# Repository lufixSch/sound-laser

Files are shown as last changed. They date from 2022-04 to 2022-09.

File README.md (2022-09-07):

# Sound Laser

This repository contains the source code, 3D Models, Circuit/PCB designs and documentation of the Sound Laser bachelor thesis at the FH JOANNEUM.

The LaTex documentation is located in [docs/build/SoundLaser_Thesis.pdf](docs/build/SoundLaser_Thesis.pdf)

## Abstract

Parametric speakers are able to transmit audible sound with a beamforming effect using ultrasonic transducers. This work will describe the development of such a speaker as well as the software necessary to operate it.

In order to build this speaker it is explained how the beamforming effect occurs and how the number of transducers as well as distance between them influences its behaviour. Furthermore non-linear acoustics and why they can demodulate amplitude or frequency modulated signals are discussed.

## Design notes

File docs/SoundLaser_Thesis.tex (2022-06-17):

\documentclass[11pt, openright]{book} % defines Basic settings for my document

\input{src/config/index}

\makeglossaries

\begin{document}
  \input{src/pages/frontmater/glossaries.tex}
  \input{src/pages/index}
\end{document}

% \enlargethispage{\baselineskip} --> Einige Zeilen trotz Seitenumbruch noch auf die vorherige Seite bringen
% \section*{xyz} --> wird nicht im Inhaltsverzeichnis gezeigt

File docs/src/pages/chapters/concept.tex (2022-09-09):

\chapter{Concept}\label{sec:concept}

% \begin{enumerate}
%   \item Ultrasonic beamforming
%   \subitem Reason:
%   \subsubitem Smaller speaker
%   \subsubitem Better focus
%   \item Hexagon module
%   \subitem Reason:
%   \subsubitem Extendable/Combinable with multiple modules
%   \subitem Amplification for each module
%   \subitem digital input
%   \item Aiming with physical contraption
%   \subitem no phase shifting necessary
%   \subsubitem to much amplifier circuits
%   \subsubitem to much digital processing -> ?proof?
% \end{enumerate}

The basic idea of this project is to design a small, autonomous module which can be combined to a larger speaker-array with improved beamforming characteristics. This will give the opportunity to compare different arrangements and numbers of modules. A single module is hexagon-shaped in order to be arranged in a honeycomb like style. Each module is equipped with an onboard DAC and amplification circuit.\p
Because of their size and their more focused dispersion characteristics, ultrasonic transducers are used in this project. How audible sound can played over an ultrasonic transducer will be explained in section \secref{sec:theory:mod}.\p
The direction of the beam is not controlled by phase shifting because, every transducer would need it's own DAC and amplifier. Alternatively the direction is altered by a mechanical contraption.

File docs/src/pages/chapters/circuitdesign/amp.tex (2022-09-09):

\section{Amplifier}\label{sec:pcb:amp}

%\begin{enumerate}
  %\item Requirements
  %\subitem VCC >= 24V -> Why
  %\item pcb layout
%\end{enumerate}

Ultrasonic transducers have to be driven with a much higher voltage and current than a DAC can provide. Therefore an amplifier circuit was designed which employs the DAC voltage as input and generates a suitable output for the array of ultrasonic transducers.

\subsection{Circuit}

The amplifier (figure \ref{fig:pcb:amp_circuit}) consists of two sections. First a non-inverting amplifier circuit to amplify the input voltage. Further, a Class B power amplifier is used so the circuit is able to drive the high capacitive load of the transducers. The whole circuit is designed for single supply because the power supply only provides a positive voltage.

\begin{figure}
  \centering
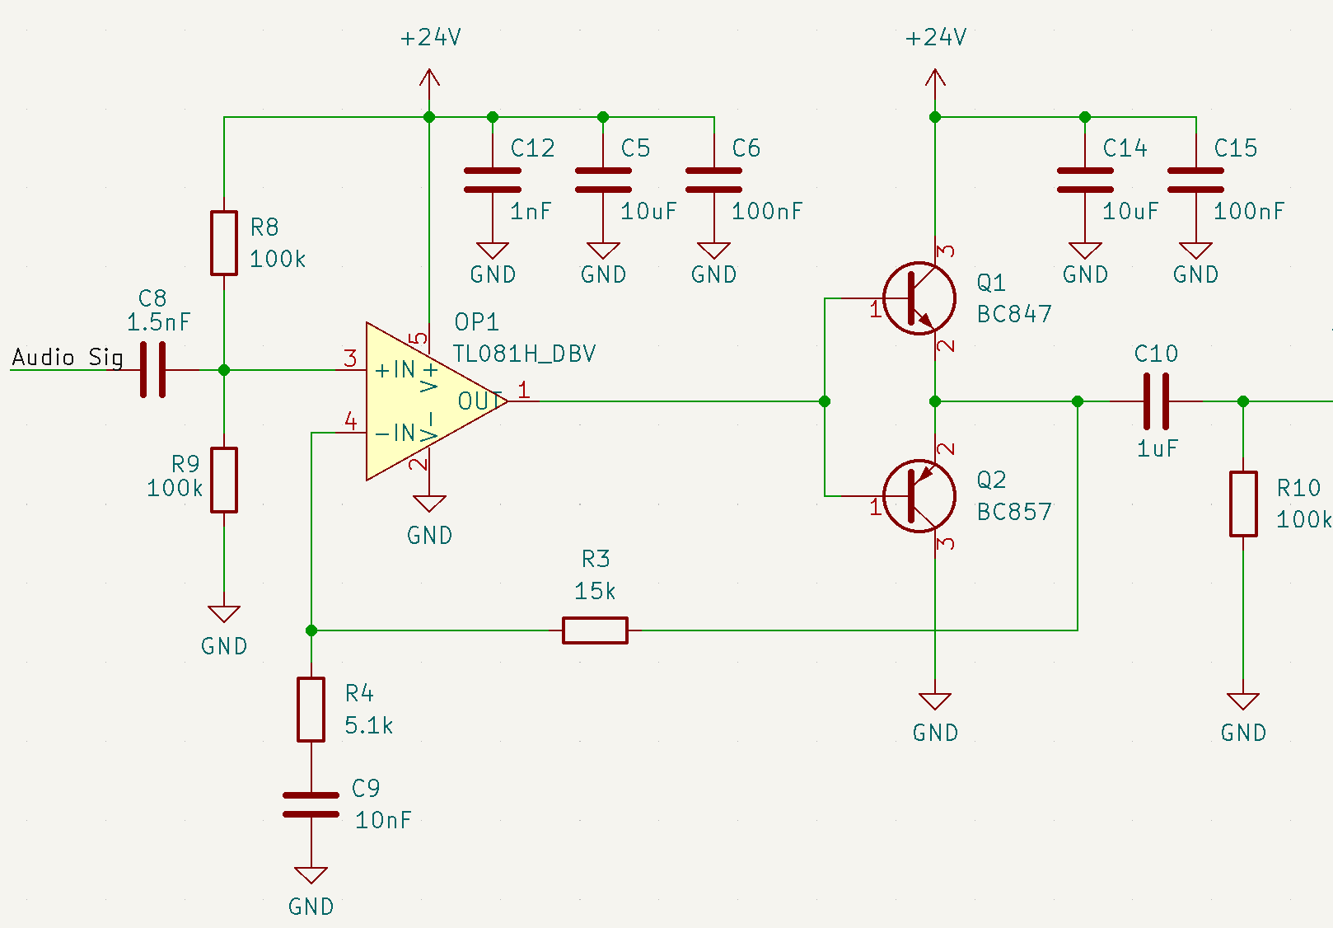
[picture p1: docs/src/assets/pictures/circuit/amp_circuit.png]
  
  \caption{Amplifier circuit design}\label{fig:pcb:amp_circuit}
\end{figure}

\subsubsection*{Voltage input}
%
\comp{C8} is used to filter the DC part of the input signal. \comp{R8} and \comp{R9} then generate a virtual ground (operating point) at $12\,V$. For AC signals a DC power supply can be seen as short circuit. This will result in \comp{R8} and \comp{R9} being parallel (figure \ref{fig:pcb:amp_hp}). Combined with \comp{C8} they create a simple high-pass which can be calculated for a specific cut-off frequency.
%
\begin{align}
  R_8 || R_9 &= \frac{1}{2} R_{8/9} \pmath
  \cfrac{U_a}{U_{in}} &= \cfrac{sC_8\cdot \frac{1}{2}R_{R8/9}}{1 + sC_8\cdot \frac{1}{2}R_{8/9}} \pmath
  f_g &= \cfrac{1}{2 \pi C_8 \cdot \frac{1}{2}R_{R8/9}} \pmath
  C_8 &= \cfrac{1}{2 \pi f_g \cdot \frac{1}{2}R_{R8/9}}
\end{align}
%
As cut-off frequency $4\,kHz$ was chosen and for \comp{R8} and \comp{R9} a value of $100\,k\Omega$ was selected. This results in a capacity of $1.5\,nF$ for \comp{C8}.
%
\begin{figure}
  \centering
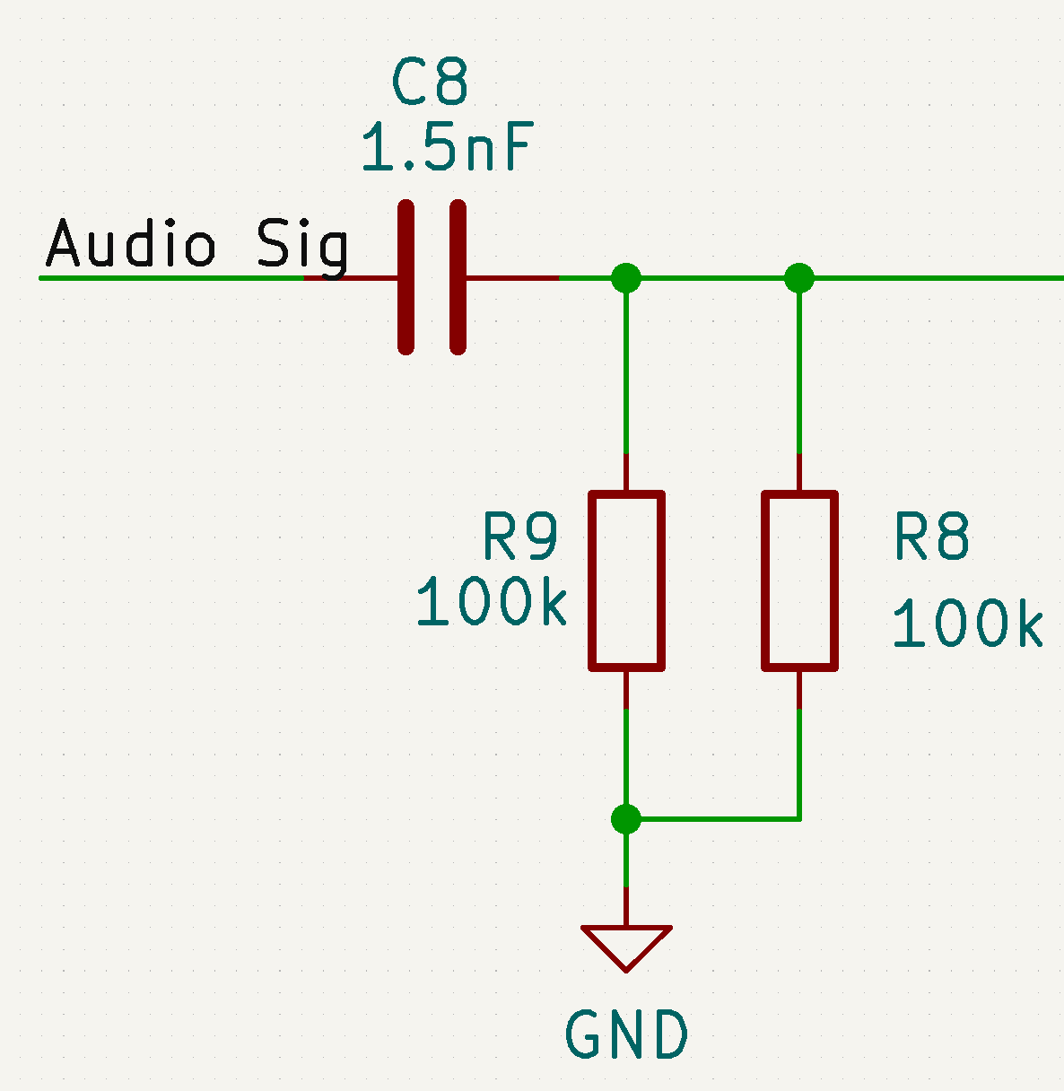
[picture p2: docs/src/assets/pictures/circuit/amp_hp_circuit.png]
  
  \caption{Input hightpass circuit}\label{fig:pcb:amp_hp}
\end{figure}
%
\subsubsection*{Feedback}
%
Due to the new operating point of the input only AC signals should be amplified by the OpAmp. This is achieved with the capacity \comp{C9} in the feedback. It blocks signals below the cut-off frequency, creating a voltage follower. For signals above the cut-off frequency the capacity \comp{C9} acts as a short circuit. The transfer function of the feedback can be used to calculate \comp{C9}. A capacitance of $10\,nF$ was selected. This results in a cut-off frequency of $3.2\,kHz$.
%
\begin{align}
  A &= \frac{1 + s C_9 (R_3 + R_4)}{1 + s C_9 R_4}\pmath
  f_g &= \frac{1}{2 \pi C_9 R_4}
\end{align}
%
The amplification can be calculated like a non-inverting amplifier. In order to take advantage of the $24\,V$ voltage range with the $4\,V$ DAC output\footnote{At this point it was not clear, that this version of the DAC would not be available} the amplification should be $4$. With $R_3 = 15\,k\Omega$ the result for \comp{R4} is $5.1\,k\Omega$.
%
\begin{align}
  V = 1 + \frac{R_3}{R_4}
\end{align}
%
As described above a power amplifier is needed to drive the high current of the ultrasonic transducers. A class B power amplifier was chosen because of its simple but powerefficient design.\cite{okorn_halbleiterschaltung_2020} Usually this design causes crossover distortion but this is solved by putting the feedback behind the power amplifier. Note, this circuit design is only possible if the OpAmp is powerfull enough to drive the base current of the transistors. A better solution for higher currents would be to use the more complex class AB power amplifier.
\subsubsection*{Voltage output}
At the output of the circuit a   filter is used to filter the $12\,V$ DC voltage caused by the voltage divider at the input.
%
\begin{align}
  A &= \cfrac{sC_{10} \cdot Z_{10}}{1 + sC_{10} \cdot Z_{10}} \pmath
  f_g &= \frac{1}{2 \pi C_{10} \cdot Z_{10}}
  Z_{10} = R_{10} || Z_M
\end{align}
%
Because the behaviour of this high-pass depends on the $ESR$ and capacity of all transducers, the size of \comp{C10} was determined empirically. The best results where achieved with $10\,uF$.

\subsection{Stability}

As mentioned before the feedback of the amplification circuit includes a capacitance. To improve stability OpAmps are usually phase compensated to represent a first order low-pass. Introducing a capacitance into the feedback could disturb the stability of the circuit.\cite{okorn_analoge_2021}\p
A general amplification circuit can be represented as shown in figure \ref{fig:pcb:amp:stab:block}. The output signal can therefore be represented as shown in equation \ref{eq:pcb:amp:stab:ua}.
%
\begin{align}
  U_a &= \underbar{A}_d (U_e - \underbar{k}U_a)\pmath
  U_a &= U_e \cfrac{\underbar{A}_d}{1 + \underbar{k}\underbar{A}_d}\label{eq:pcb:amp:stab:ua}
\end{align}
%
\begin{figure}[ht]
  \centering
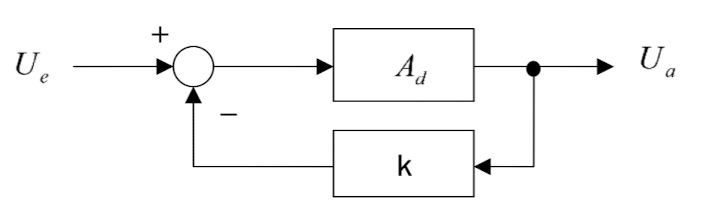
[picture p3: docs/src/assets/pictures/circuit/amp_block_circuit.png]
  
  \caption{Block circuit of an amplification circuit\cite{okorn_analoge_2021}}\label{fig:pcb:amp:stab:block}
\end{figure}
%
This results in an unstable circuit if $kA_d = -1$.
%
\begin{align}
  |\underbar{k}\underbar{A}_d| &= 1\pmath
  \arg(\underbar{k}\underbar{A}_d) &= - 180^\circ
\end{align}
%
In order to verify the stability, $\underbar{A}_d$ and $\underbar{k}$ of the amplifier circuit where calculated.
%
\begin{align}
  \underbar{A}_d &= \frac{A_0}{1 + \frac{s}{w_g}}\pmath
  w_g &= 2\pi \cdot \frac{GBW}{A_0}
\end{align}
%
The open loop gain $A_0$ as well as the $GBW$ were taken from the data sheet.\cite{texas_instruments_tl08xx_2021}
%
\begin{align}
  \underbar{k} &= \frac{1 + s C_9 R_4}{1 + s C_9 (R_4 + R_3)}
\end{align}
%
Figure \ref{fig:pcb:amp:stab:loop_gain} shows the bode plot of $\underbar{k}\underbar{A}_d$. It can be observed that the phase is $90^\circ$ when the magnitude reaches $0dB$. This means the circuit has a phase reserve of $90^\circ$, which is enough to keep it stable.
%
\begin{figure}
  \centering
  
  \caption{Loop gain}\label{fig:pcb:amp:stab:loop_gain}
\end{figure}
%

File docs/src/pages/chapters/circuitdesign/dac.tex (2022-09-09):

\section{DAC}
%
%\begin{enumerate}
%  \item Requirements
%  \subitem >= 120ks/s
%  \subitem Fast enough digital interface
%  \subsubitem package size * sampling rate
%  \subitem Handsolder SMD package
%  \subitem 5V VCC
%  \item component/model decision
%  \item I2C vs. SPI
%  \item pcb layout
%  \item Problems with the DAC
%\end{enumerate}
%
The DAC in the Circuit is used to generate an analog voltaged signal from the signal recorded and modulated by a Raspberry Pi or microcontroller.\p
%
As described in section \secref{sec:theory:mod} the frequency of the modulated signal goes up to $50\,kHz$.
In order to comply with the sampling theorem, the sampling frequency of the DAC should be at least $100\,kHz$. Therefore the digital interface has to bee fast enough, even if up to 7 modules are connected at the same time. Additionally, the DAC should work with $5\,V$ supply voltage and an internal reference voltage.\p
%
I2C only allows a maximum clockspeed of $5\,MHz$ (Ultra Fast-mode).\cite{nxp_i2c-bus_2021} The length of a $10\,bit$ or $12\,bit$ DAC sample is usually about $32\,bit$ ($8\,bit$ Address + RW, $8\,bit$ config, $10 - 12\,bit$ Data, $4 - 6\,bit$ Don't care). As shown in equation \ref{eq:pcb:dac_fs} this only allows a sampling rate up to $156.25\,kHz$ even if only one module is connected. Because every module needs to be addressed individually, the sampling rate would drop to $22.321\,kHz$ when using all seven modules. For this reason SPI was selected as serial interface. The clock frequency of the SPI module is only limited by the system clock and the receiver is selected by a separate chip select pin which reduces the packet size of one sample to $24\,bit$. Because every module gets the same signal one CS pin for all DACs can be used.\p
%
%First the 12bit DAC \dots was selected. It uses a I2C interface which allows to connect the Raspberry Pi and the Speaker with only two wires independent of the number of modules. Unfortunately the DAC only supports a clock frequency up to $400kHz$ and each sample has a packetsize of $32bit$. As shown in equation \ref{eq:pcb:fs} this only allows a sampling rate up to $12500Hz$ even if only one module is connected.
%
\begin{align}
  f_{s,1} &= \frac{5MHz}{32bit} = \frac{5 \frac{Mbit}{s}}{32bit} = 156.25kHz \label{eq:pcb:dac_fs}\\[1em]
  f_{s, 7} &= \frac{fs_1}{7} = \frac{156.25kHz}{7} = 22.321kHz
\end{align}
%
The DAC, selected for this project, is the LTC2640 from Linear Technology. It comes with an SPI interface and a sampling rate up to $125\,kHz$. Depending on the model it supports a resolution of $8$, $10$ or $12\,bit$. The DAC has an internal reference voltage of $2.5\,V$ or $4.096\,V$. $12\,bit$ resolution with $4.096\,V$ reference voltage would be the ideal configuration of this DAC. Because of component shortage only the DAC with $2.5\,V$ reference voltage was available. This model produces a smaller output voltage which can be compensated by increasing the gain of the amplifier circuit described in section \secref{sec:pcb:amp}.\cite{linear_technology_ltc2640_2017}
%
\begin{figure}
  \centering
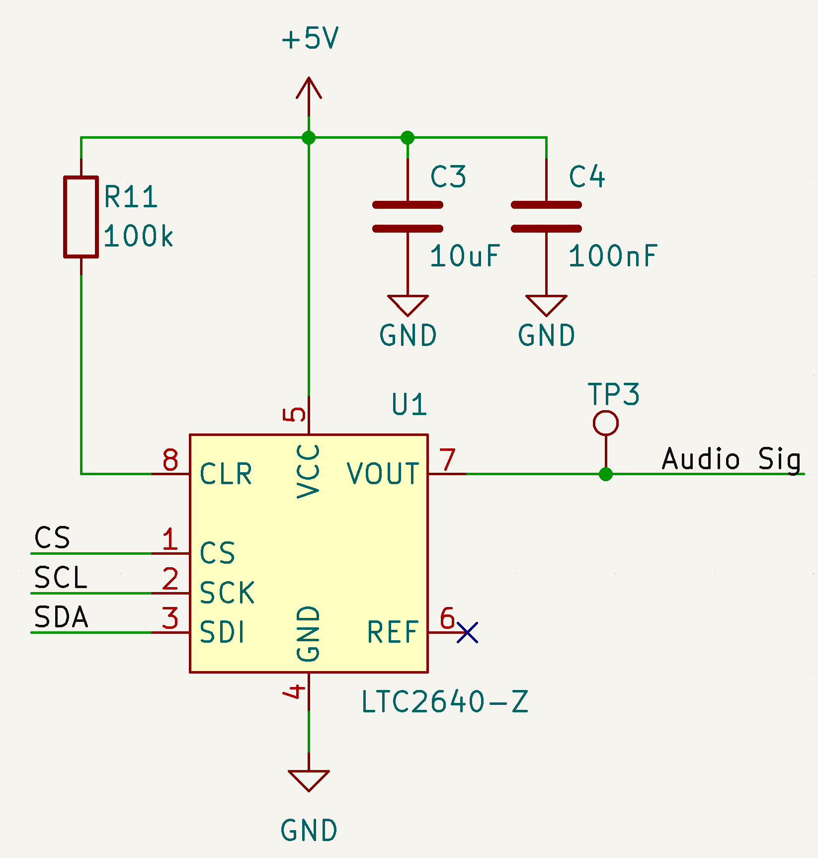
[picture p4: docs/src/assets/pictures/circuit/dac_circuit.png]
  
  \caption{DAC Circuit design}\label{fig:pcb:dac_circuit}
\end{figure}

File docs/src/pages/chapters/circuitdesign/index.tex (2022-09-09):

\chapter{Circuit and PCB Design}
%
Using the results from the last section the circuit for the individual modules has been designed. The 3D model of the resulting PCB is shown in figure \ref{fig:pcb}
%
\input{src/pages/chapters/circuitdesign/dac.tex}
\input{src/pages/chapters/circuitdesign/transducers.tex}
\input{src/pages/chapters/circuitdesign/amp.tex}
\input{src/pages/chapters/circuitdesign/powersupply.tex}
%
\begin{figure}[ht]
  \centering
  \begin{subfigure}[b]{0.6\textwidth}
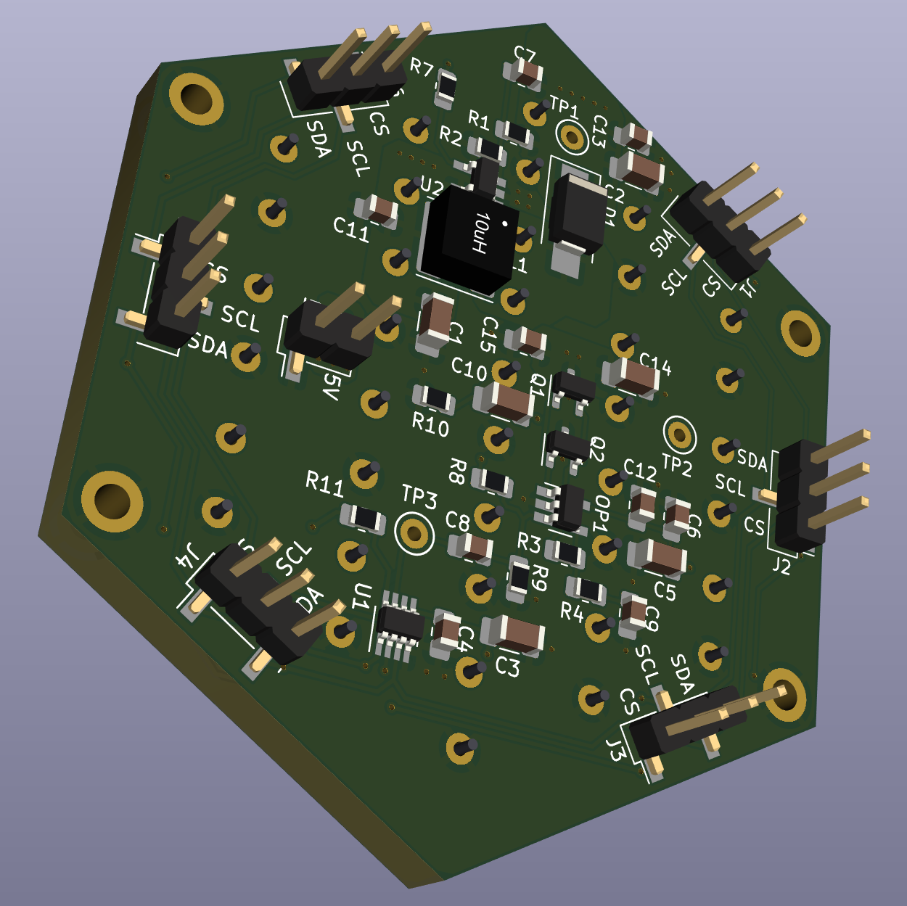
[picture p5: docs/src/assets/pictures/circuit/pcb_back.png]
    
    \caption{Back}
    \label{fig:pcb:back}
  \end{subfigure}
  \\
  \begin{subfigure}[b]{0.6\textwidth}
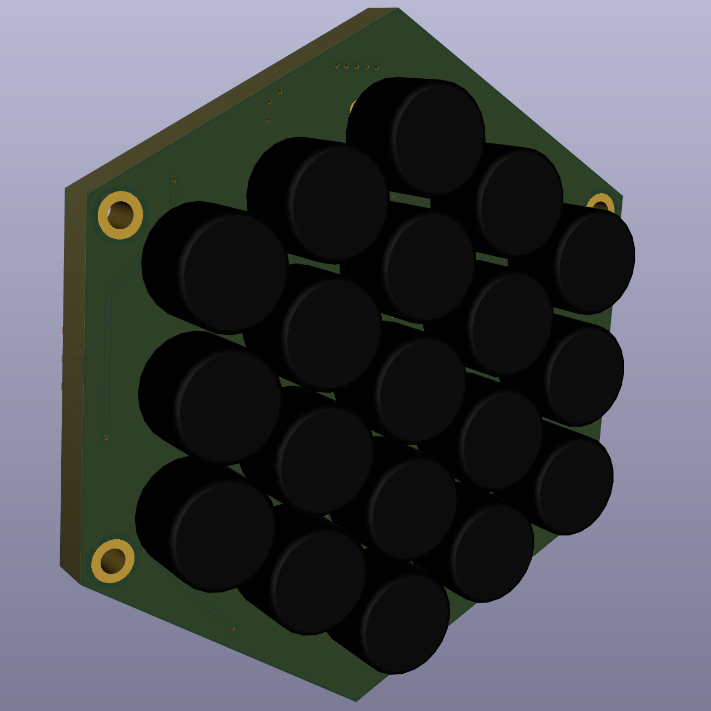
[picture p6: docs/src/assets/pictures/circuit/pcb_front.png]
    
    \caption{Front}
    \label{fig:pcb:front}
  \end{subfigure}
  \caption{3D model of the PCB layout}
  \label{fig:pcb}
\end{figure}
%

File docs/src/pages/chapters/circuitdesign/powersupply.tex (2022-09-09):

\section{Power Supply}

%\begin{enumerate}
  %\item Circuit design
  %\subitem In -> Out Voltage
  %\subitem Capacitors
  %\subitem Inductor
  %\item PCB layout
  %\subitem Max current strength
  %\subsubitem > 2A -> Changed later
  %\subitem Parasitic effects/interferences
%\end{enumerate}

Because the speaker will be used with a Raspberry Pi or microcontroller, it should be compatible with an input voltage of $5V$. In order to provide the $24V$ needed by the amplifier circuit a boost converter is used.\p
The power supply should at least provide $200mA$ so it can power the OpAmp and additional elements. Apart from that, a higher switching frequency helps to reduce interferences at the speaker output.\p
%
Considering those requirements the LM2735 boost converter was chosen. Because the power usage of the ultrasonic transducers was unknown in the beginning of this project the power supply provides up to $3A$ output current. The output voltage can be adjusted between $3V$ and $24V$.\cite{texas_instruments_lm2735-q1_2018}

\subsection{Circuit}

Figure \ref{fig:pcb:power_circuit} shows the circuit of the power supply. The feedback was designed by using the equation given in the datasheet.
Note that in equation \ref{eq:pcb:power:vout} \comp{R1} and \comp{R2} are switched compared to the circuit in the datasheet.
%
\begin{align}
  R_1 &= \left(\frac{V_{out}}{V_{ref}} - 1\right) \cdot R_2\label{eq:pcb:power:vout}
  &\mathrm{with~} V_{ref} = 1.255V,~V_{out} = 24V
\end{align}
%
The dimensions of \comp{L1} as well as the capacity \comp{C7} and the diode \comp{D1} were taken from the examples in the datasheet.
%
\begin{figure}[ht]
  \centering
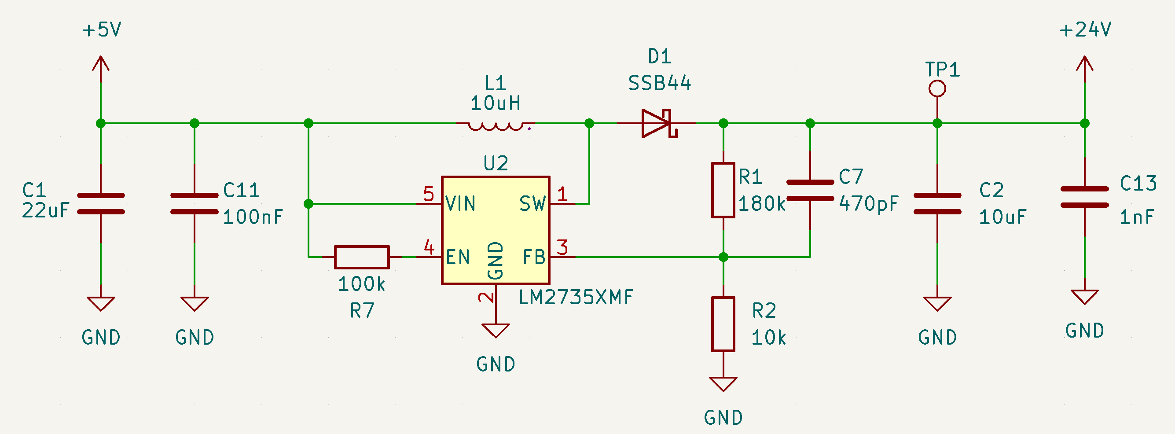
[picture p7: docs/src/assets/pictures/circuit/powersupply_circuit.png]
  
  \caption{Powersupply circuit design}\label{fig:pcb:power_circuit}
\end{figure}

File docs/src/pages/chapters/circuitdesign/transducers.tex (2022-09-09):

\section{Ultrasonic Transducers}

The ultrasonic transducer chosen for this project is the CUSA-T80-15-2400-TH. It has an operating frequency of $40\,kHz$ and tolerates a supply voltage up to $80\,V$.\cite{cui_devices_cusa-t80-15-2400-th_2020}\newpage
\noindent One module uses $19$ transducers which are connected in parallel as shown in figure \ref{fig:pcb:transducer_circuit}. In order to create the aspired beamforming effect the transducers are evenly distributed on the pcb (figure \ref{fig:pcb:front}).
%
\begin{figure}
  \centering
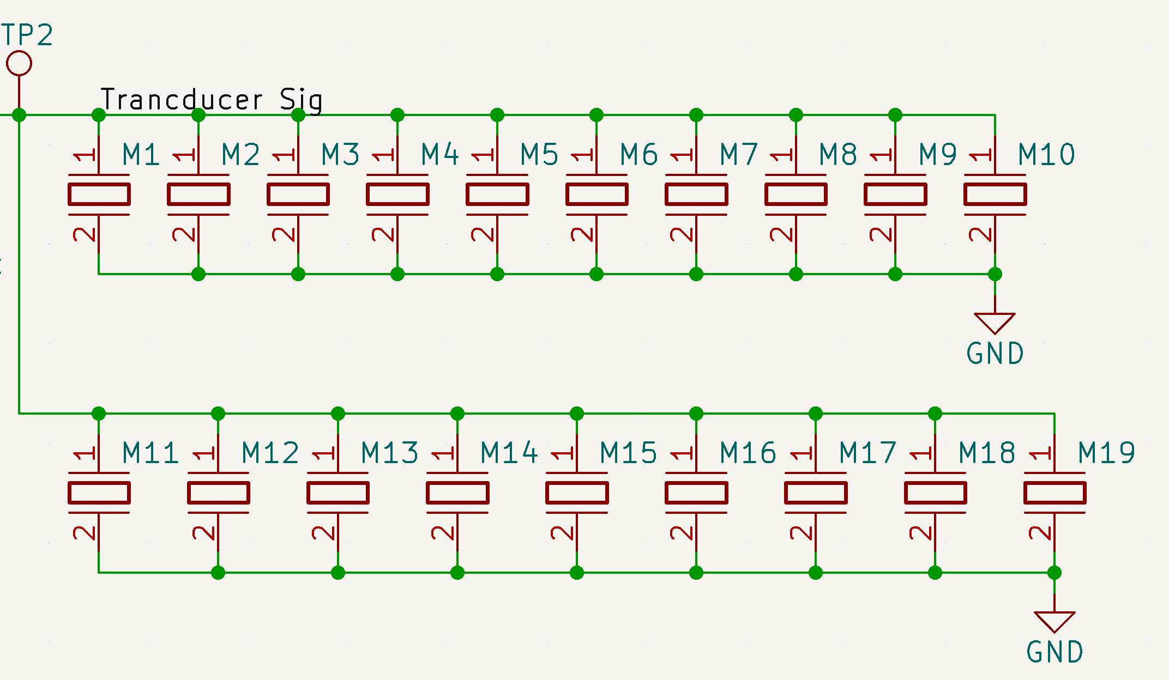
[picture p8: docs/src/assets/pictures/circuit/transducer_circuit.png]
  
  \caption{Transducer circuit design}\label{fig:pcb:transducer_circuit}
\end{figure}

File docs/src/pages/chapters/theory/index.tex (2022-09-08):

\chapter{Theoretical Background}
%
This section will explain the theoretical background of creating a beamforming speaker using ultrasonic transducers. Furthermore the results are used to predict the theoretical behaviour of the speaker in different configurations.
%
\input{src/pages/chapters/theory/beamforming.tex}
\input{src/pages/chapters/theory/modulation.tex}

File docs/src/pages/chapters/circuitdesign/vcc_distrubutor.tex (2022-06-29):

\section{VCC Distributor}

\begin{enumerate}
  \item Explanation
  \item Current strength
\end{enumerate}

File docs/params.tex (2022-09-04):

\newcommand{\thesisTitle}{Sound Laser}
\newcommand{\thesisSubtitle}{Ultrasonic beamforming using a parametric array}
\newcommand{\shortTitle}{Sound Laser}

\renewcommand{\author}{Lukas Schüttler}
\newcommand{\supervisor}{Florian Mayer}

\newcommand{\assessors}{$ASSESSOR1$ \\ $ASSESSOR2$}

\newcommand{\finishedDate}{\today}

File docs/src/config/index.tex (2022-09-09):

\input{src/config/imports.tex}

%# Page layout ------------------------------------------------------------------------
\geometry{a4paper,twoside,%
	%textheight=205mm, %246mm,%
	textwidth=160mm,%
	top = 3cm,
	bottom = 4.5cm,
	heightrounded=false,% round textheight to multiple of lines (avoids overfull vboxes)
	ignoreall=true,% do not include header, footer, and margins in calculations
	marginparsep=5pt,% marginpar only used for signs (centered), thus only small sep. needed
	marginparwidth=10mm,% prevent margin notes to be out of page
	hmarginratio=1:2,
	voffset = 2.25mm,
	%headheight = 16mm,
	headsep = 9mm,
	footskip = 13mm
}

\linespread{1.4}

%% CLEAR DOUBLE-PAGE
% redefine cleardoublepage...
\makeatletter
\renewcommand{\cleardoublepage}{\clearpage\if@twoside\ifodd\c@page\else\thispagestyle{plain}\hbox{}\newpage\if@twocolumn\hbox{}\newpage\fi\fi\fi}
% ...and define empty double page (e.g., for title sheet)
\newcommand{\emptydoublepage}{\clearpage\if@twoside\ifodd\c@page\else\thispagestyle{empty}\hbox{}\newpage\if@twocolumn\hbox{}\newpage\fi\fi\fi}%
% ...and also an empty single page
\newcommand{\emptypage}{\clearpage\thispagestyle{empty}\hbox{}\newpage\if@twocolumn\hbox{}\newpage\fi}%
\makeatother

%%%%% Correct Even and Odd Pages %%%%%
\let\tmp\oddsidemargin
\let\oddsidemargin\evensidemargin
\let\evensidemargin\tmp
\reversemarginpar

%# Font Configuration ------------------------------------------------------------------------
\newcommand{\ChapterFont}{qag}
\newcommand{\WorkingFont}{\rmdefault}
\renewcommand{\familydefault}{\WorkingFont}
\normalfont

\renewcommand{\cftchapfont}{\bf\large\fontfamily{\sfdefault}\selectfont}
\renewcommand{\cftpartfont}{\bf\large\fontfamily{\sfdefault}\selectfont}

%# Headings ------------------------------------------------------------------------

\renewcommand*\chaptermark[1]{\markleft{\thechapter~#1}}
\renewcommand*\sectionmark[1]{\markright{\thesection~#1}}

\clearpairofpagestyles
\ohead[\shortTitle]{\footnotesize\headmark}%

\ofoot[\ifthenelse{\equal{\thepage}{}}{\pagemark}{--~~\pagemark~~--}]{\ifthenelse{\equal{\thepage}{}}{\pagemark}{--~~\pagemark~~--}}

%#-- Chapter, Section etc. ------------------------------------------------------------------------

\titleformat{\part}[display]
   {\sffamily\bfseries\fontsize{26}{26}\selectfont\filcenter}
   {\sffamily\bfseries\fontsize{30}{22}\selectfont\partname{} \thepart}
   {0.5em}
   {}

\titleformat{\chapter}[display]
{\sffamily\bfseries\fontsize{22}{22}\selectfont}%\
{
\begin{tikzpicture}[overlay]
	\node (CoolTitle) at (12,1) [opacity=0.325]{};
	\node (titleNumber) at ($(CoolTitle)+(3,0)$) {\textcolor{black!80}{\fontfamily{\ChapterFont}\bfseries\Large\fontsize{80}{80}\selectfont\thechapter}};
\end{tikzpicture}
}
{0.05em}%
{\vspace{0.25ex}\filleft}%
%
\titleformat{\section}{\Large \bfseries \sffamily}{\thesection}{1 em}{}
\titleformat{\subsection}{\large \bf \sffamily}{\thesubsection}{1 em}{}
\titleformat{\subsubsection}{\large \bf \sffamily}{\thesubsubsection}{1 em}{}

%# Setup Counter ------------------------------------------------------------------------
\counterwithout{footnote}{chapter}

\counterwithin{figure}{section}
\counterwithin{table}{section}
\counterwithin{equation}{section}
\AtBeginDocument{\counterwithin{lstlisting}{section}}
\setcounter{secnumdepth}{3}

\captionsetup{font=small, labelfont=bf, labelformat=simple, justification=raggedright, singlelinecheck=false}

%# Table Setup ------------------------------------------------------------------------
\setlength{\tabcolsep}{6pt}
\renewcommand{\arraystretch}{1.2}

\newcolumntype{C}[1]{>{\centering\arraybackslash}p{#1}}
\newcolumntype{R}[1]{>{\raggedleft\arraybackslash}p{#1}}

%# TikZ Configuration ------------------------------------------------------------------------
\usetikzlibrary{matrix,calc,positioning,arrows,shapes}
\usetikzlibrary{decorations.pathreplacing}

%# Colors ------------------------------------------------------------------------
\definecolor{mGreen}{rgb}{0,0.6,0}
\definecolor{mGray}{rgb}{0.5,0.5,0.5}
\definecolor{mPurple}{rgb}{0.58,0,0.82}
\definecolor{backgroundColour}{rgb}{0.95,0.95,0.92}
\definecolor{DENcol}{RGB}{35,171,196} % Department Colour
\definecolor{DENcol10}{RGB}{245, 245, 245}

%# Setup Hyperlink ------------------------------------------------------------------------
\hypersetup{
    colorlinks=true,
    linkcolor=black,
    filecolor=black,
    urlcolor=black,
    pdfpagemode=FullScreen,
}

%# Setup Listing ------------------------------------------------------------------------
\lstloadlanguages{Bash,Matlab,[ANSI]C,[LaTeX]TeX, C++, Python}

\newcommand{\lstbase}{\fontsize{8}{8}\normalfont\sffamily}

\lstset{
  frame=top,frame=bottom,
  basicstyle=\lstbase,
  commentstyle=\color{mGreen},
  keywordstyle=\color{magenta},
  numberstyle=\tiny\color{DENcol},
  stringstyle=\color{mPurple},            % the size of the fonts that are used for the code
	stepnumber=1,                           % the step between two line-numbers. If it is 1 each line will be numbered
	numbersep=4pt,                          % how far the line-numbers are from the code
	tabsize=2,                              % tab size in blank spaces
	extendedchars=true,                     %
	breaklines=true,                        % sets automatic line breaking
	captionpos=t,                           % sets the caption-position to top
	mathescape=true,
	showspaces=false,                       % Leerzeichen anzeigen ?
	showtabs=false,                         % Tabs anzeigen ?
	xleftmargin=15pt,
	framexleftmargin=14pt,
	framexrightmargin=9pt,
	framexbottommargin=9pt,
	framextopmargin=9pt,
	showstringspaces=false,      % Leerzeichen in Strings anzeigen ?
	numbers = left,
%	linewidth = 150mm,
	language=C++
}

%# Setup mdframed ------------------------------------------------------------------------
\mdfsetup{%
middlelinecolor=red,
middlelinewidth=2pt,
backgroundcolor=DENcol!10,
roundcorner=10pt,
topline = false,
bottomline = false,
rightline = false,
linecolor = DENcol,
linewidth = 10pt}

%\makeindex %create Index (Inhaltsangabe)
%\pagestyle{fancy}

%%%% GET RID OF OVERFULL BOXING WARNINGS %%%%
%\overfullrule=5pt
\setlength{\headheight}{1.1\baselineskip}
\raggedbottom

%# Hyphenation --------------------------------------------------------------------------
\hyphenation{tem-per-a-ture-changes}

\input{src/config/commands.tex}

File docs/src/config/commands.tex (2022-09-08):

\newcommand{\p}{\vspace{4pt}\\}
\newcommand{\pmath}{\\[0.8em]}
\newcommand{\comp}[1]{\textbf{#1}}
\newcommand{\lstpython}[1]{\lstinline[basicstyle=\normalfont\sffamily, language=Python]{#1}}
\newcommand{\lstcpp}[1]{\lstinline[basicstyle=\normalfont\sffamily]{#1}}

\newcommand{\ie}{i.\,e.}
\newcommand{\Ie}{I.\,e.}
\newcommand{\eg}{e.\,g.}
\newcommand{\Eg}{E.\,g.}

\newcommand{\smallheight}{5cm}
\newcommand{\mediumheight}{8cm}
\newcommand{\largeheight}{10cm}

\newcommand{\secref}[1]{\ref{#1}}

\input{params.tex}

%?\newcommand{\documenTitle}{Laborübung 1~-~Elementare Schaltungen}
%?\newcommand{\firstStudent}{Lukas Schüttler}
%?\newcommand{\secondStudent}{Tim Schmid}
%?
%?\newcommand{\lecture}{Einführung in die Elektrotechnik}
%?\newcommand{\semester}{2. Semester}
%?
%?\newcommand{\lectureDate}{16.10.19}
%?\newcommand{\finishedDate}{---}

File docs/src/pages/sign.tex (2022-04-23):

\vspace{24pt}
\begin{tabular*}{\linewidth}{@{}l@{\extracolsep{\fill}} ll@{}}
    \vspace{0cm}&&\\[-2em]
    \vspace{0cm}&\makebox[5cm]{\hrulefill} & \makebox[5cm]{}\\
    Graz, den \finishedDate&\author&\\[15ex]% adds space between the two sets of signatures
    \end{tabular*}

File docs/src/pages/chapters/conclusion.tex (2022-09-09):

\chapter{Conclusion}

%\begin{enumerate}
%  \item Achievements
%  \item Problems
%  \subitem Hardware
%  \subsubitem DAC
%  \subsubitem Bandwidth
%  \subsubitem Serial interface
%  \subitem Software
%  \subsubitem Modulation
%  \subsubitem Timpe vector will cut the carrier signal
%  \subsubitem Realtime
%  \item Follow up
%  \subitem Larger speaker
%  \subitem Hardware modulation
%  \subitem Communication with uC
%  \subitem Integration with AI Motion Lab
%  \subitem Extended Speaker Control interface
%\end{enumerate}

\subsubsection*{Summary}

In this project it was achieved to created a parametric speaker array which emits audible sound with clear beamforming behaviour. A circuit to operate this speaker was designed and a software was developed which receives audio over bluetooth modulates the signal and transmits it to the speaker. Additionally, a construction to tilt the speaker was built.
%
\subsubsection*{Follow Up}
%
Even though the circuit did not work in the end, this can easily be fixed by replacing the DAC with an other model. The performance problems of the software can be fixed as well by porting the code onto a realtime capable device. A compromise would be to record and modulate the signal on the Raspberry Pi and transmit it to a microcontroller in a large buffer. Due to that, the microcontroller transmits the signal with the given sampling rate.\p
%
Following this project, an in-depth analysis of different modulation techniques, for example pulse modulation or single sideband AM, could be conducted. Furthermore, it would be interesting to examine the behaviour of multiple speaker modules as this would increase the beamforming characteristics.
%
\subsubsection*{Ressources}
%
The source code of the software as well as 3D Modells for the tilting mechanism and a KiCAD project for the PCB design can be accessed on Github: \href{https://github.com/lufixSch/sound-laser}{https://github.com/lufixSch/sound-laser}.

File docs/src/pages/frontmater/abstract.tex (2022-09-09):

%%%%% ThesisTemplate ECE / AEE %%%%%%
%
% Created by Mayer Florian October/2016
% v1.0

\emptydoublepage \thispagestyle{empty} \vspace*{1cm}

{\hfill\fontfamily{\sfdefault}\bfseries\fontsize{22}{22}\selectfont{Abstract}} \vspace*{1cm}

\noindent
Parametric speakers are able to transmit audible sound with a beamforming effect using ultrasonic transducers. This work will describe the development of such a speaker as well as the software necessary to operate it.\p
In order to build this speaker it is explained how the beamforming effect occurs and how the number of transducers as well as distance between them influences its behaviour. Furthermore non-linear acoustics and why they can demodulate amplitude or frequency modulated signals are discussed.

\emptydoublepage \thispagestyle{empty} \vspace*{1cm}

{\hfill\fontfamily{\sfdefault}\bfseries\fontsize{22}{22}\selectfont{Kurzbeschreibung}} \vspace*{1cm}

\noindent
Parametrische Lautsprecher sind in der Lage, hörbaren Schall mit richtverhalten unter Verwendung von Ultraschalllautsprechern zu übertragen. In dieser Arbeit wird die Entwicklung eines solchen Lautsprechers sowie die, für seinen Betrieb erforderliche, Software beschrieben.\p
Um diesen Lautsprecher zu bauen, wird außerdem erklärt, wie der Beamforming-Effekt zustande kommt und wie die Anzahl der Ultraschalllautsprechern sowie der Abstand zwischen ihnen sein Verhalten beeinflusst. Darüber hinaus wird auf nichtlineare Akustik eingegangen und erklärt, warum durch sie amplituden- oder frequenzmodulierte Signale demodulieren werden können.

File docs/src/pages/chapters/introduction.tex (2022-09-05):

\chapter{Introduction}

%\begin{enumerate}
%  \item Phased Arrays
%  \subitem Sonar
%  \subitem Radiotechnolog
%  \item Task
%  \subitem audio beamforming
%  \subitem beamforming
%  \item Usage
%  \subitem "Private" without headset
%  \subitem Spacial Audio
%\end{enumerate}

In communications technology antenna arrays are used to increase directivity of antennas and therefore amplify their reception power in the main radiation direction.\cite{netzberger_kommunikationstechnologie_2021-2} This technology can not only be used for electromagnetic waves but any kind of wave. Parametric arrays achieve a similar beamforming effect in acoustics which is utilised in non invasive medical imaging applications\cite{novelline_squires_1997}\cite{konofagou_focused_2001} or seismic profiling\cite{muir_highresolution_1984}.\p
The aim of this thesis is to develop a speaker which generates a beam of audible sound with the use of a parametric array.
%The result of this project will not be a finished product but a prototype. Therefore no attention is given to applicable directives or standards.\p
In the following chapters the development of the speaker prototype as well as its acoustic behaviour will be explained respectively.

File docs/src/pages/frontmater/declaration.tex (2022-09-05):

%%%%% ThesisTemplate ECE / AEE %%%%%%
%
% Created by Mayer Florian October/2016
% v1.0

\emptydoublepage \thispagestyle{empty} \vspace*{1cm}

% \ifthenelse{\equal{\DocumentLanguage}{de}}{
{\hfill\fontfamily{\sfdefault}\bfseries\fontsize{16}{16}\selectfont{Obligatory declaration}}\vspace*{1cm}\\
%
I hereby confirm and declare that the present Bachelor's thesis
%/Master's thesis
was composed by myself without any help from others and that the work contained herein is my own and that I have only used the specified sources and aids. The uploaded version is identical to any printed version submitted.\p
I also confirm that I have prepared this thesis in compliance with the principles of the FH JOANNEUM Guideline for Good Scientific Practice and Prevention of Research Misconduct.\p
I declare in particular that I have marked all content taken verbatim or in substance from third party works or my own works according to the rules of good scientific practice and that I have included clear references to all sources.\p
The present original thesis has not been submitted to another university in Austria or abroad for the award of an academic degree in this form.\p
I understand that the provision of incorrect information in this signed declaration may have legal consequences.
%
%\input{src/pages/sign.tex}
%	\par\vspace*{4cm}
%	\centerline{
%	\begin{tabular}{m{1.5cm}cm{1.5cm}m{3cm}m{1.5cm}cm{1.5cm}}
%	\cline{1-3} \cline{5-7}
%	& Date & & & & (Signature) &\\
%	\end{tabular}}
% }

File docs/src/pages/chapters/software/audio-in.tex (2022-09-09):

\subsection{Audio Input}\label{sec:software:rec}
%
There are different methods to connect an external audio source to the Raspberry Pi. The Raspberry provides an AUX port where the microphone line could be used as input. An alternative would be to use an external USB audio card or an audio card HAT\footnote{Hardware attached on top} with a dedicated AUX IN port. The third variant would be to connect the device over bluetooth.\p
%
Because of the current shortage off Raspberry Pi's and Raspberry Pi accessories a HAT is not an option. In order to use the Raspberry as a bluetooth speaker some complicated configuration and programming of the bluetooth interface has to be done, which would take a lot of time. The integrated audio interface of the Raspberry Pi could be used but it is known to have a mediocre sound quality. Therefore the best option would be an external USB audio card. However during research the open source tool BlueZ-Alsa\cite{bokowy_bluez-alsa_2022} was found. This program makes it possible to configure the Raspberry Pi as bluetooth audio speaker with one simple shell-command. The connected device (Audio in/out depending on the configuration) can then be accessed using the Advanced Linux Sound Architecture (ALSA).
%
\subsubsection*{ALSA Interface}

The interface to ALSA is the HAL class \lstcpp{PCM}. On construction it takes a device name, channel count and sampling rate. With those parameters the ALSA PCM device is configured using the \textbf{ALSA} C library (listing \ref{lst:software:audio_in:pcm_config}).\cite{noauthor_alsa_nodate} The configuration is based on an example of the ALSA Audio API tutorial from Paul Davis.\cite{davis_tutorial_2002}
%
\begin{mdframed}
\begin{lstlisting}[caption=ALSA interface configuration, label=lst:software:audio_in:pcm_config]
PCM::PCM(std::string device_name, char channel_cnt, uint32_t fs) {
  int i;
  int err;
  snd_pcm_format_t format = SND_PCM_FORMAT_S16_LE;

  if ((err = snd_pcm_open(&capture_handle, device_name.c_str(), SND_PCM_STREAM_CAPTURE, 0)) < 0) {
    std::cerr << "cannot open audio device (" << snd_strerror(err) << ")\n";
    exit(1);
  }

  if ((err = snd_pcm_hw_params_malloc(&hw_params)) < 0) {
    std::cerr << "cannot allocate hardware parameter structure (" << snd_strerror(err) << ")\n";
    exit(1);
  }

  if ((err = snd_pcm_hw_params_any(capture_handle, hw_params)) < 0) {
    std::cerr << "cannot initialize hardware parameter structure (" << snd_strerror(err) << ")\n";
    exit(1);
  }

  if ((err = snd_pcm_hw_params_set_access(capture_handle, hw_params, SND_PCM_ACCESS_RW_INTERLEAVED)) < 0) {
    std::cerr << "cannot set access type (" << snd_strerror(err) << ")\n";
    exit(1);
  }

  if ((err = snd_pcm_hw_params_set_format(capture_handle, hw_params, format)) < 0) {
    std::cerr << "cannot set sample format (" << snd_strerror(err) << ")\n";
    exit(1);
  }

  if ((err = snd_pcm_hw_params_set_rate(capture_handle, hw_params, (unsigned int)fs, 0)) < 0) {
    std::cerr << "cannot set sample rate (" << snd_strerror(err) << ")\n";
    exit(1);
  }

  if ((err = snd_pcm_hw_params_set_channels(capture_handle, hw_params, channel_cnt)) < 0) {
    std::cerr << "cannot set channel count (" << snd_strerror(err) << ")\n";
    exit(1);
  }

  if ((err = snd_pcm_hw_params(capture_handle, hw_params)) < 0) {
    std::cerr << "cannot set parameters (" << snd_strerror(err) << ")\n";
    exit(1);
  }

  snd_pcm_hw_params_free(hw_params);

  if ((err = snd_pcm_prepare(capture_handle)) < 0) {
    std::cerr << "cannot prepare audio interface for use (" << snd_strerror(err) << ")\n";
    exit(1);
  }

  format_width = snd_pcm_format_width(format) / 8;
  format_zero = 0;
  format_max = pow(2, snd_pcm_format_width(format)) / 2;
}
\end{lstlisting}
\end{mdframed}
%
\newpage\noindent
After the configuration the method \lstcpp{readFrames()} can be used to read a given number of samples (Listing \ref{lst:software:audio_in:pcm_read}). The method will block the code execution until all frames are received or an error occurs.
%
\begin{mdframed}
\begin{lstlisting}[caption=Method for reading frames from an ALSA device, label=lst:software:audio_in:pcm_read]
void PCM::readFrames(sample_t* buffer, size_t frames) {
  int err;

  if ((err = snd_pcm_readi(capture_handle, buffer, frames)) != frames) {
      std::cerr << "read from audio interface failed (" << snd_strerror(err) << ")\n";
      exit(1);
    }
}
  \end{lstlisting}
\end{mdframed}
%
\subsubsection*{Record Audio}
%
The \lstcpp{PCM} class is initialized in \lstcpp{AudioProcessor::configure()}. This instance is then used in the method \lstcpp{record()} shown in listing \ref{lst:software:audio_in:record}. The method creates a loop in which a set of samples is read into a buffer and then pushed into the \lstcpp{AudioProcessor::samples} queue. \lstcpp{record()} can be executed directly or by calling \lstcpp{record_thread()} which creates a new thread for the loop.

\begin{mdframed}
\begin{lstlisting}[caption=Record loop, label=lst:software:audio_in:record]
void AudioProcessor::record() {
  std::cout << "Run Record Loop\n";
  size_t len = frame_size;

  std::vector<sample_t> buffer(len);

  while (true) {
    pcm_dev->readFrames(buffer.data(), frame_size);
    samples.push(buffer);
  }
}
\end{lstlisting}
\end{mdframed}

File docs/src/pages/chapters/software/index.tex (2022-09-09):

\chapter{Software}

The software of the speaker has two main goals: Controlling the movement and playing an audio signal from an external source over SPI. Because both parts of the software don't need to interact with each other it was decided to split them up into two separate programs. The Speaker control is written in python but the Sound playback is written in C++ to increase performance.\p
%
A Raspberry Pi 3 Model B+ was chosen to run the software. With its Linux operating system it provides an easy way to parallize tasks. The Raspberry Pi also has a SPI interface and enough PWM pins to control the Servo Motors.\cite{van_loo_bcm2836_2014}

\section{Sound Playback}

The sound playback program starts by reading samples from a connected audio device. Those samples are then modulated and sent over SPI with the right sampling rate. In order to generate a fluent audio playback the tasks where splitted into three threads. The whole sequence of the program is shown in figure \ref{fig:software:sound_sequence}.\p
%
Reading audio samples and modulating them is done in the class \lstcpp{AudioProcessor}. The SPI transmission is handled in the class \lstcpp{Speaker}. Both classes are built with the singleton pattern.
%
\begin{figure}
  \centering
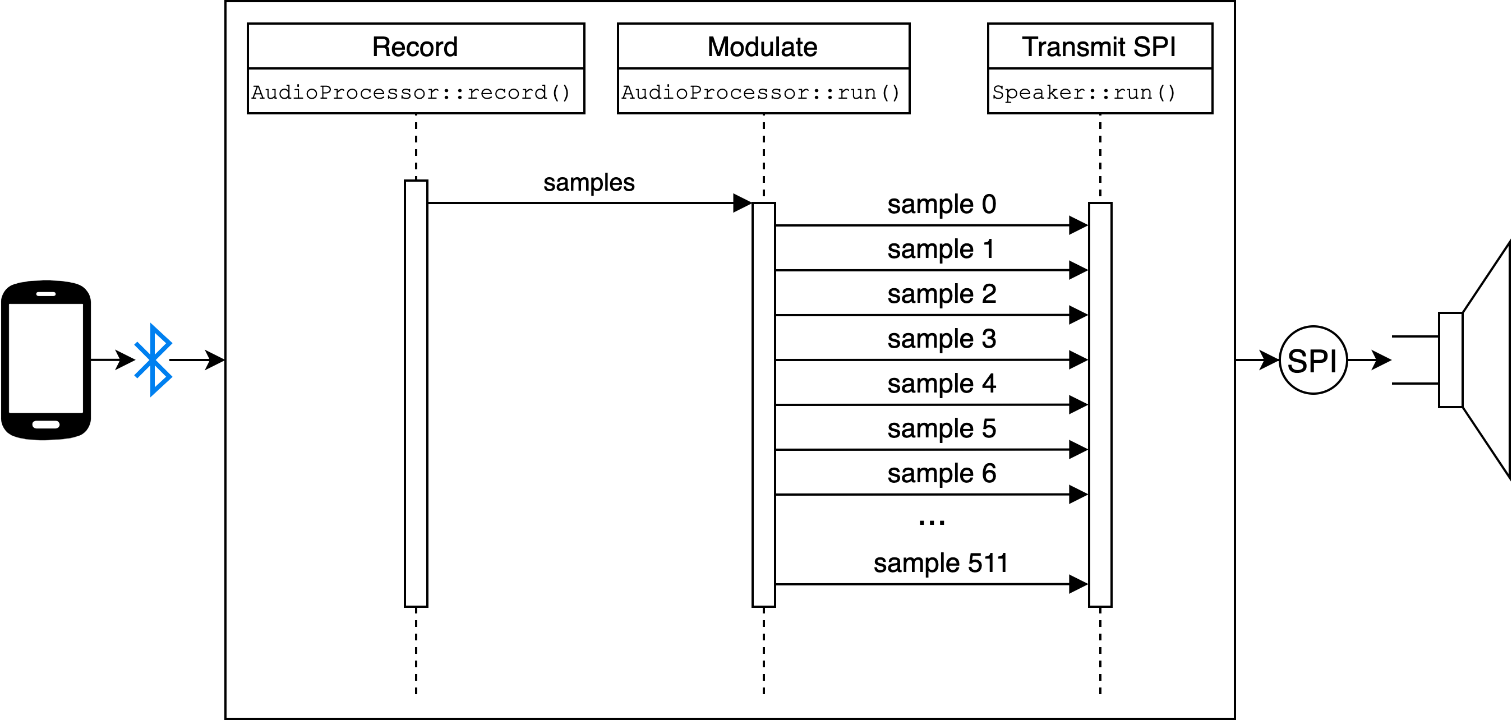
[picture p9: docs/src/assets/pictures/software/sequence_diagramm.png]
  
  \caption{Sound playback sequence diagram}\label{fig:software:sound_sequence}
\end{figure}
\p
The communication between threads is handlend with a queue. The implementation shown in listing \ref{lst:software:queue} makes the \lstcpp{std::queue} threadsafe by using a lock to access the underlying queue and also blocks the thread if no data is available. This is usefull, because there is no need to send data over SPI when no new sample is generated.\p
%
A hardware abstraction layer is used to separate logic and hardware interfaces.
%
\begin{mdframed}
\begin{lstlisting}[caption=Threadsafe and blocking queue, label=lst:software:queue]
template <class T> class BlockingQueue : public queue<T> {
  public:
  void push(T item) {
    {
      unique_lock<std::mutex> lck(lock);
      queue<T>::push(item);
    }
    not_empty.notify_one();
  }

  T pop() {
    unique_lock<std::mutex> lck(lock);
    not_empty.wait(lck, [this]() { return queue<T>::size() > 0; });

    T value = queue<T>::front();
    queue<T>::pop();
    return value;
  }

  bool notEmpty() { return !queue<T>::empty(); }

  private:
  std::mutex lock;
  condition_variable not_empty;
};
\end{lstlisting}
\end{mdframed}

\input{src/pages/chapters/software/audio-in.tex}
\input{src/pages/chapters/software/modulation.tex}
\input{src/pages/chapters/software/spi.tex}\clearpage

\section{Speaker Movement}
\input{src/pages/chapters/software/movement.tex}

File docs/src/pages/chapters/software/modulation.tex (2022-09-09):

\subsection{Modulation}
%
The modulation process is realised in \lstcpp{AudioProcessor::run()} (Listing \ref{lst:software:mod:loop}). To make switching between modulation techniques easier the methods for calculation the modulation itself are provided by the \lstcpp{Modulator} class.\p
%
\begin{mdframed}
\begin{lstlisting}[caption=Audio processing loop, label=lst:software:mod:loop]
void AudioProcessor::run() {
  std::cout << "Run Audio Processor\n";

  const auto& speaker = Speaker::instance();
  Modulator mod(sampling_rate, frame_size, speaker->sampling_rate, 40000);

  while (true) {
    const auto& buffer = samples.pop();

    for (const auto t : mod.time) {
      const auto sig = mapValue(buffer.at(floor(t * sampling_rate)));
      const auto sample = mod.AM(sig, t, 0.5f, 0.8f); // AM
      // const auto sample = mod.FM(sig, t, 1.0f, 0.15f);   // FM
      speaker->samples.push(speaker->mapSample(sample));
    }
  }
}
\end{lstlisting}
\end{mdframed}
%
First the samples captured from the audio input are fetched from the \lstcpp{AudioProcessor::samples} queue. As the signal recorded with ALSA is a regular audio signal the sampling rate goes up to $48\,kHz$ depending on the configuration. The resulting signal however should have a sampling rate above $100\,kHz$. Therefore the signal needs to be resampled. This can be realised with different forms of interpolation. In this example the zero order hold variant is used.\p
%
As the \lstcpp{Modulator} class is instantiated a time vector with the target sampling rate and a size corresponding to the number of recorded samples is created. The modulation is calculated for every sample by iterating over the time vector.\p
%
Listing \ref{lst:software:mod:am} and \ref{lst:software:mod:fm} show the C++ implementations of the AM and FM explained in section \secref{sec:theory:mod}.
%
\begin{mdframed}
\begin{lstlisting}[caption=Amplitude modulation, label=lst:software:mod:am]
float Modulator::AM(float signal, float t, float U0, float m) {
  float c = sin(carrier * t);
  return U0 * (1 + m * signal) * c;
}
\end{lstlisting}
\end{mdframed}
%
\begin{mdframed}
\begin{lstlisting}[caption=Frequency modulation, label=lst:software:mod:fm]
float Modulator::FM(float signal, float t, float U0, float m) {
  float w0 = carrier;
  return U0 * sin(w0 * (1 + m * signal) * t);
}
\end{lstlisting}
\end{mdframed}

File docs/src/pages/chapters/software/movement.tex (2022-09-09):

\subsection{Speaker Control}

The movement of the speaker is controlled by two servo motors which are connected to the GPIO Pins of the Raspberry Pi. The GPIO Pins can be controlled in Python using the \textbf{GPIOZero} library\cite{nuttall_gpio_2021} . It provides a class \lstpython{servo} which takes the pin to which the servo is connected. The servo can then be positoned by setting \lstpython{servo.value} to a value between $0$ and $1$. Note that \lstpython{servo} works with every pin but just pin \textbf{12} and \textbf{13} support hardware PWM. For the other pins the PWM will be created by software. This variant usually generates some jitter which makes the servo tremble. To make sure the hardware PWM is used for pin \textbf{12} and \textbf{13} the pin factory should be changed to \lstpython{PiGPIOFactory} (Listing \ref{lst:software:mov:pin_factory}).\cite{nuttall_gpio_2021}
%
\begin{mdframed}
\begin{lstlisting}[language=Python, caption=Changing the pin factory, label=lst:software:mov:pin_factory]
from gpiozero.pins.pigpio import PiGPIOFactory
from gpiozero import Device
Device.pin_factory = PiGPIOFactory()
\end{lstlisting}
\end{mdframed}
%
The configuration and control of the servo is handled in the HAL class \lstpython{ServoHAL} (Listing \ref{lst:software:mov:servo}). The class provides options to invert the servo or set an offset if the servo arm is not centered properly. \lstpython{set_position()} takes an angle between $-90^\circ$ and $90^\circ$ and sets the servo position accordingly.
%
\begin{mdframed}
\begin{lstlisting}[language=Python, caption=Servo configuration and control, label=lst:software:mov:servo]
class ServoHAL(HAL):

def __init__(self, pin: int, inverted: bool, offset: float):
    self.pin = pin
    self.offset = offset
    self.inverted = -1 if inverted else 1

    self.pwm = Servo(pin, initial_value=self._map_position(0), min_pulse_width=0.615 /
                      1000, max_pulse_width=2.495 / 1000)

def _map_position(self, angle: float):
    pos = self.inverted * (angle + self.offset) / 90

    if pos > 1: pos = 1
    if pos < -1: pos = -1

    return pos

def set_position(self, pos: float):
    self.pwm.value = self._map_position(pos)

def close(self):
    self.pwm.value = None
\end{lstlisting}
\end{mdframed}
%
In the class \lstpython{SpeakerControl} the \lstpython{ServoHAL} class is used to actually tilt the speaker. The class defines two servos for rotation around the x- and y-axis. Tilting can be initiated using the \lstpython{tilt_x()} or \lstpython{tilt_y()} method one of which is shown in listing \ref{lst:software:mov:tilt}. Both methods take the tilting angle in degree an map it to the corresponding servo postion using \lstpython{_map_position()} which implements the calculations from section \secref{sec:const:tilt}. The result is used to change the servo position.
%
\begin{mdframed}
\begin{lstlisting}[language=python, caption=Method for titling the speaker around the x-axis, label=lst:software:mov:tilt]
def tilt_x(self, angle: float):
  servo_pos = self._map_position(angle)

  print(f"Tilt X - {servo_pos}")

  self._x_servo.set_position(servo_pos)
  self.x_angle = angle
\end{lstlisting}
\end{mdframed}

\subsection{Control Interface}
%
The control interface consists of a website where a user can set the tilting angle of the speaker and an API over which the speaker is actually controlled. Both are created in Python with the \textbf{aiohttp} library.\cite{noauthor_aiohttp_nodate}

\subsubsection*{API}

The API is generated in the class \lstpython{API}. It registers the routes \textit{tilt/x}, \textit{tilt/y} and \textit{tilt} as shown in listing \ref{lst:software:mov:api}.
\textit{tilt/x} and \textit{tilt/y} are used to post a new titling angle to the server. \textit{tilt} returns the current tilting position around the x- and y-axis in JSON format.
%
\begin{mdframed}
\begin{lstlisting}[language=Python, caption=Control interface API, label=lst:software:mov:api]
class API:
  def __init__(self, server: web.Application) -> None:
      self.server = server
      self._create_api()

  def _create_api(self):
      self.speaker_control = SpeakerControl(12, 13)
      self.server.router.add_post("/tilt/x", self._tilt_x_handler)
      self.server.router.add_post("/tilt/y", self._tilt_y_handler)
      self.server.router.add_get("/tilt", self._get_tilt_handler)

  async def _tilt_x_handler(self, req: web.Request):
      try:
          content = json.loads(await req.text())
          angle = content["value"]
          self.speaker_control.tilt_x(angle)

          res = dict(success=True, message="")
      except Exception as err:
          res = dict(success=True, message=getattr(
              err, "message", repr(err)))

      return web.Response(text=json.dumps(res), content_type='application/json')

  async def _tilt_y_handler(self, req: web.Request):
      try:
          content = json.loads(await req.text())
          angle = content["value"]
          self.speaker_control.tilt_y(angle)

          res = dict(success=True, message="")
      except Exception as err:
          res = dict(success=True, message=getattr(
              err, "message", repr(err)))

      return web.Response(text=json.dumps(res), content_type='application/json')

  async def _get_tilt_handler(self, req: web.Request):
      return web.Response(
          text=json.dumps(dict(
              x=self.speaker_control.x_angle,
              y=self.speaker_control.y_angle
          )), content_type='application/json')
\end{lstlisting}
\end{mdframed}

\subsubsection*{Website}

Even though the API can be used to control the speaker programmatically a website provides an easy interface for manual inputs.\p
%
In order to publish a website, a webserver needs to be configured. This is done in the class \lstpython{Webserver}. As shown in listing \ref{lst:software:mov:webserver} the constructor takes a reference to the \textbf{aiohttp} Application and a path to the directory containing the \textit{.html}, \textit{.js} and \textit{.css} files. The webserver checks all files contained in this directory and registers new routes for each file so they can be accessed from a webbrowser.
%
\begin{mdframed}
\begin{lstlisting}[language=Python, caption=Minimal python webserver, label=lst:software:mov:webserver]
class Webserver:
  def __init__(self, server: web.Application, web_directory: str) -> None:
      self.server = server
      self.web_path = web_directory
      self._create_webserver()

  def _create_webserver(self):
      files = os.listdir(self.web_path)
      routes = self._create_routes(files)
      for route in routes:
          self.server.router.add_get(f"/{route}", self._webadress_handler)

      self.web_routes = routes

  async def _webadress_handler(self, req: web.Request):
      path = req.path.lstrip("/")
      route_config = self.web_routes[path]
      with open(os.path.join(self.web_path, route_config[0])) as f:
          return web.Response(text=f.read(), content_type=route_config[1])

  def _create_routes(self, files: List[str]) -> Dict[str, Tuple[str, str]]:
      routes = {}
      for file in files:
          route = file
          split_file = os.path.splitext(file)
          content_type = f"text/{split_file[1].lstrip('.')}"
          if split_file[1] == ".html":
              if split_file[0] == "index":
                  route = ""
              else:
                  route = f"{split_file[0]}"
          if split_file[1] == ".js":
              content_type == f"text/javascript"

          routes[route] = (file, content_type)

      return routes
\end{lstlisting}
\end{mdframed}
%
\newpage\noindent
The design of the website is shown in figure \ref{fig:software:mov:website}. When the site is loaded it uses the \textit{tilt} route to get the current position of the speaker. Now the two text fields can be used to enter a new angle for rotation around the x- or y-axis. Clicking on the \textbf{move} button will post this input to \textit{tilt/x} and \textit{tilt/y} respectively.
%
\begin{figure}[ht]
  \centering
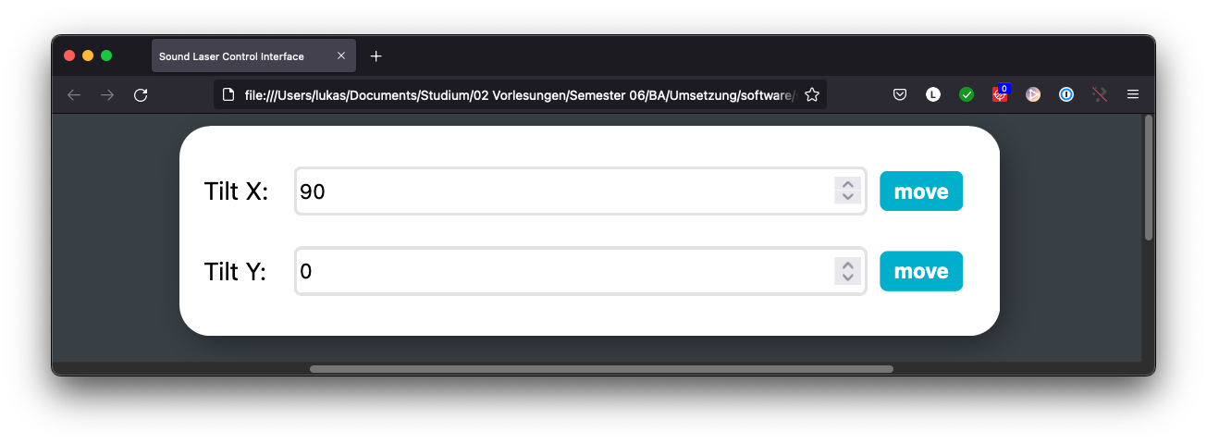
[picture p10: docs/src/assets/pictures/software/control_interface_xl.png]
  
  \caption{Graphical control interface of the speaker}\label{fig:software:mov:website}
\end{figure}

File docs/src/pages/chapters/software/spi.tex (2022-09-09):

\subsection{SPI (Audio Output)}

\subsubsection*{SPI Interface}

As described before the sampling rate of the SPI output should be at least $100\,kHz$. This means every $10\,\mu s$ one packet has to be submitted. The Linux OS for the Raspberry Pi provides a SPI implementation which can be accessed via C++ or Python. After putting the SPI write function into a loop without any pause or other calculations in between it became noticeable that this implementation is only able to send one package every $50\,\mu s$ to $80\,\mu s$. This problem can be solved with the \textbf{bcm2835} C library.\cite{mccauley_bcm2835_nodate} This library bypasses the linux drivers and directly accesses the bcm2835 SOC from the Raspberry Pi. It provides interfaces for GPIO pins, PWM and SPI as well as \lstcpp{bcm2835_delayMicroseconds()} function which is much more accurate than the builtin C++ functions.\p
%
The SPI configuration is put into the HAL class \lstcpp{SPI} (See listing \ref{lst:software:spi:conf})
%
\begin{mdframed}
\begin{lstlisting}[caption=SPI configuration, label=lst:software:spi:conf]
SPI::SPI() {
  if (!bcm2835_spi_begin()) {
    throw std::runtime_error("bcm2835_spi_begin failed. Are you running as root??");
  }

  bcm2835_spi_setBitOrder(BCM2835_SPI_BIT_ORDER_MSBFIRST);
  bcm2835_spi_setDataMode(BCM2835_SPI_MODE0);
  bcm2835_spi_setClockDivider(BCM2835_SPI_CLOCK_DIVIDER_64);
  bcm2835_spi_chipSelect(BCM2835_SPI_CS0);
  bcm2835_spi_setChipSelectPolarity(BCM2835_SPI_CS0, LOW);
}
\end{lstlisting}
\end{mdframed}
%
The \lstcpp{SPI} class provides the method \lstcpp{write()} which takes a byte array and writes it on the SPI bus (Listing \ref{lst:software:spi:write}). \lstcpp{write()} uses the method \lstcpp{transfer()} which passes through the function \lstcpp{bcm2835_spi_transfernb()} from the \textbf{bcm2835} library. This function needs two buffers. One contains the data to be transmitted. The second one is used to save the received data.
%
\begin{mdframed}
\begin{lstlisting}[caption=Method for writing data onto the SPI bus, label=lst:software:spi:write]
void SPI::write(char* data, uint32_t size) {
  this->transfer(data, this->rx_buffer, size);
}
\end{lstlisting}
\end{mdframed}
%
\lstcpp{rx_buffer} is a $4096$ Byte array where the unused, received data from the \lstcpp{write()} method is dumped.
%
\subsubsection*{Transmit Audio}

The audio transmission over SPI is performed in the class \lstcpp{Speaker}. The method \lstcpp{Speaker::run()} creates a loop in which the next audio sample is fetched from the \lstcpp{Speaker::samples} queue and transmitted over SPI. After the transmission the loop is paused to reach the right sampling rate. The sleep time is calculated dynamically depending on the time the sending of the data took. The coresponding code is shown in listing \ref{lst:software:spi:loop}.
\begin{figure}[ht]
\begin{mdframed}
\begin{lstlisting}[caption=Audio transmission loop, label=lst:software:spi:loop]
void Speaker::run() {
  std::cout << "Run Speaker Loop with a max delay of " << delay << "\n";

  long long diff;
  uint64_t delay = (uint64_t)(1000000000 / sampling_rate);
  char data[WORD_SIZE] = { conf, 0x00, 0x00 };
  auto start = std::chrono::high_resolution_clock::now();

  while (true) {
    auto sample = samples.pop();
    data[1] = (char)(sample >> 4);
    data[2] = (char)((sample & 0x000F) << 4);

    spi.write(data, WORD_SIZE);

    auto diff = std::chrono::duration_cast<std::chrono::nanoseconds>(std::chrono::high_resolution_clock::now() - start)
                    .count();
    auto diff_abs = (uint64_t)diff <= delay ? diff : delay;
    auto sleep = (delay - diff_abs) / 1000;

    bcm2835_delayMicroseconds(sleep);
    start = std::chrono::high_resolution_clock::now();
  }
}
\end{lstlisting}
\end{mdframed}
\end{figure}
%
\subsubsection*{Linux Realtime}

Because the signal is split into a fixed sampling rate, timing is really important for this task. As described before this is improved by using \lstcpp{bcm2835_delayMicroseconds()} over builtin C++ sleep functions. Nevertheless, because of the nature of Linux scheduling, it can not be quaranteed that the thread will pause exactly the given delay every time. Linux scheduling is fair. This means every process gets its time on the CPU. If a process was paused and needs to wake up again, it has to wait for the current process on the CPU to finish its time slice. For time relevant processes Linux provides a feature to bypass this behaviour. A process can be given a scheduling priority. When this process wants to wake up and a process with lower or no priority uses the CPU it is paused immediately and the new proccess does not need to wait. This still does not quarantee a fixed sleep time because there could always be a task with higher priority but it reduces the risk of waiting.\cite{faschingbauer_realtime_nodate}\p
%
The scheduling priority can be changed using \lstcpp{pthread_setschedparam()} from the \textbf{PThread} library (Listing \ref{lst:software:spi:rt}). It takes a priority between $1$ and $99$, where $99$ is the highest priority and $1$ is the lowest. A priority of $1$ or $2$ is usually sufficient because most processes do not have any scheduling priority.\cite{noauthor_pthread_setschedparam3_nodate}
%
\begin{mdframed}
\begin{lstlisting}[caption=Example for creating a thread with realtime priority, label=lst:software:spi:rt]
std::thread* Speaker::run_thread() {
  loop = new std::thread(&Speaker::run, this);
  pthread_t id = (pthread_t)(loop->native_handle());

  sched_param sched_params = { 2 };
  pthread_setschedparam(id, SCHED_FIFO, &sched_params);

  return loop;
}
\end{lstlisting}
\end{mdframed}
%
All threads used in the program are started with a priority of $1$ or $2$ as shown in listing \ref{lst:software:spi:rt}.

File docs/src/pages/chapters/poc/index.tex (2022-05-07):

\chapter{Proof of Concept}

\begin{enumerate}
  \item Idea
  \item AI Motion Lab
  \item Data
  \subitem Reading
  \subitem Sending/Recieving
  \item Coordinate/Servo position calculation
\end{enumerate}

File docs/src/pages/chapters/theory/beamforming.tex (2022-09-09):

\section{Beamforming}\label{sec:theory:beam}

%\begin{enumerate}
%  \item Explanation
%  \subitem straight line
%  \subitem phase shifting
%  \item Ideal calculation
%  \subitem Number of speakers
%  \subitem Distance of speakers
%  \item Real-World behavior/limitations
%  \subitem Real speaker distance
%  \subitem Real speaker characteristics
%\end{enumerate}

Beamforming is a concept used for emitting and receiving signals. It describes the technique of bundling a signal so it is only transmitted into or received from one direction. Because in this thesis beamforming is used with a speaker the following explanation will use an emitter as example but the calculations would work in exactly the same way for a receiver.\cite{van_veen_beamforming_1988}\p
%
In order to produce the beamforming effect for one dimension you need multiple emitters arranged in one line.
If the receiver is far enough away from the emitters the directional vector of the waves can be viewed as parallel. When the receiver is positioned directly in front of the emitters (\(0^\circ\)) all waves reach it at the same time (see figure \ref{fig:theory:beam:array_straight}).
When the position of the receiver is rotated (\(\pm \varphi^\circ\)) the waves have to travel different distances (See figure \ref{fig:theory:beam:array_angle}). Therefore, they reach the receiver with a phase shift. Depending on the position of the receiver and distance of the emitters the waves will cancel each other out.
%
\begin{figure}
  \centering
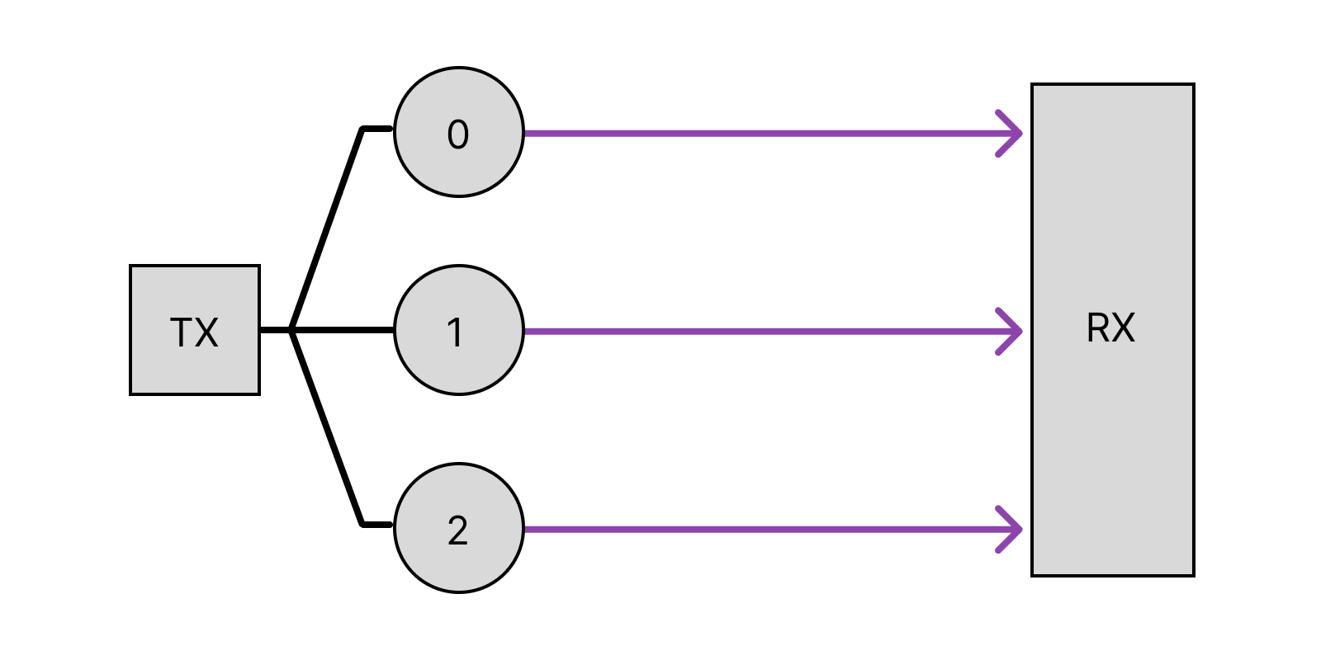
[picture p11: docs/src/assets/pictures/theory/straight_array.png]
  
  \caption{Phased array with the receiver positioned at $0^\circ$}\label{fig:theory:beam:array_straight}
\end{figure}
\begin{figure}
  \centering
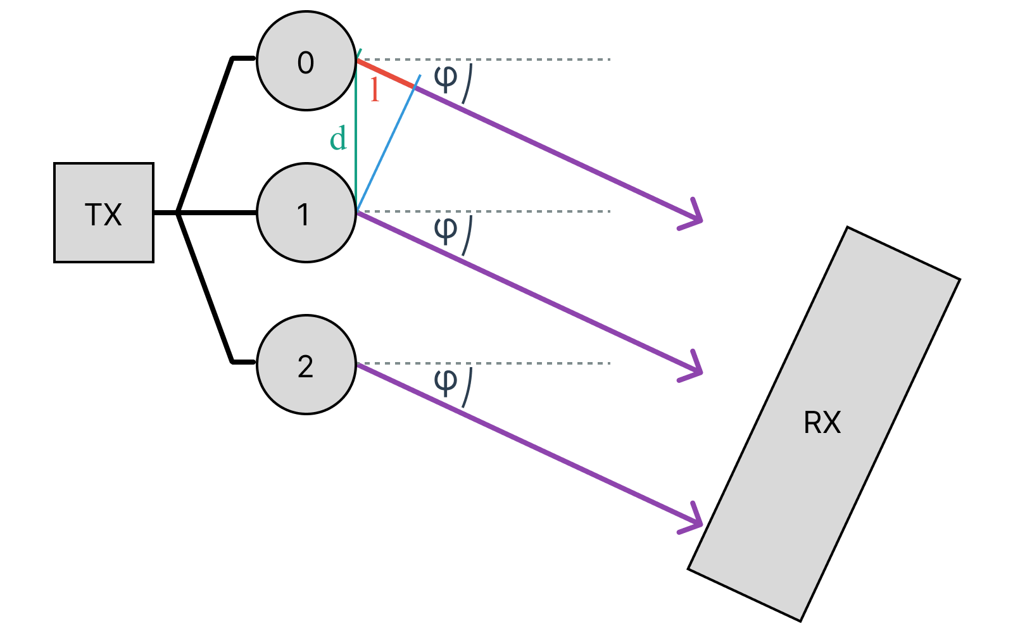
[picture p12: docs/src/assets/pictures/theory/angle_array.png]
  
  \caption{Phased array with the receiver positioned at $25^\circ$}\label{fig:theory:beam:array_angle}
\end{figure}
\p
The difference in travel distance of two waves depending on the angle \(\varphi\) can be described as follows:
%
\begin{align}
  l(\varphi) &= \sin \varphi \cdot d\label{eq:theory:beam:dist}
\end{align}
%
Where \(d\) describes the spacing between the emitters.\newpage
%
\noindent Given the connection between distance $d$, time $t$, velocity $v$, wavelength $\lambda$ and frequency $f$, equation \ref{eq:theory:beam:dist} can be used to calculate the phaseshift $\Phi$ between those two waves.\cite{elert_speed_2021}\cite{cassidy_understanding_2002}
%
\begin{align}
  t(\varphi)     &= \frac{l}{v} = \frac{d}{v} \sin \varphi \\[1em]
  \Phi(\varphi)  &= \omega \cdot t = \frac{\omega}{v} d \cdot \sin \varphi \\[1em]
  \mathrm{with~} \lambda &= \frac{v}{f} \implies \frac{\omega}{v} = \frac{2\pi \cdot f}{v} = \frac{2\pi}{\lambda} \\[1em]
  \Phi(\varphi)  &= \frac{2\pi}{\lambda} d \cdot \sin \varphi \label{eq:theory:beam:single_phaseshift}
\end{align}
%
Equation \ref{eq:theory:beam:single_phaseshift} can also be used for a whole array of emitters, where $\Phi(\varphi)$ describes the phaseshift between two adjacent emitters. To get the phaseshift of the $n$th speaker relative to the first one ($n=0$) the phaseshifts $\Phi(\varphi)$ just need to be summed up.
%
\begin{align}
  \Phi(\varphi, n) &= n \cdot \frac{2\pi}{\lambda} d \cdot \sin \varphi
\end{align}
%
Given an array of $N$ spherical emitter generating a cosine wave (\(s_e(t)\)), the received signal (\(s(t)\)) would be the sum of all waves with their coresponding phaseshift (equation \ref{eq:theory:beam:sig_sum}).\cite{curtis_technology_uk_ltd_time_1998}
%
\begin{align}
  s_e(t, \varphi, n) = \cos (\omega t + n \cdot \frac{2\pi}{\lambda} d \cdot \sin \varphi )\label{eq:theory:beam:sig}\\[1em]
  s(t, \varphi) = \sum_{n = 0}^{N - 1} s_e(t, \varphi, n)\label{eq:theory:beam:sig_sum}
\end{align}
%
For an array of two emitters the signals would look as shown in figure \ref{fig:theory:beam:time}.
Figure \ref{fig:theory:beam:n2_d.5} displays the resulting signal power in a polar diagram.\cite{curtis_technology_uk_ltd_time_1998}\p
%
It can be observed, that the amplitude of the resulting signal is reduced the larger \(\varphi\) gets. Until both waves cancel each other out at \(90^\circ\).
%
\begin{figure}
  \centering
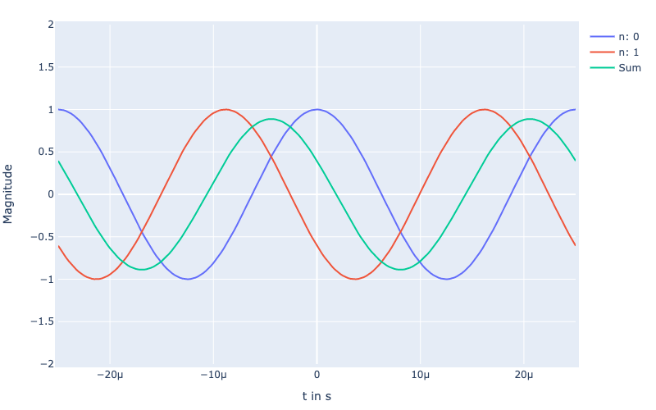
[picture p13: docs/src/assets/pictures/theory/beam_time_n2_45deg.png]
  
  \caption{Signals of two emitters in a phased array ($\varphi=45^\circ$)}
  \label{fig:theory:beam:time}
\end{figure}
%
\begin{figure}
  \centering
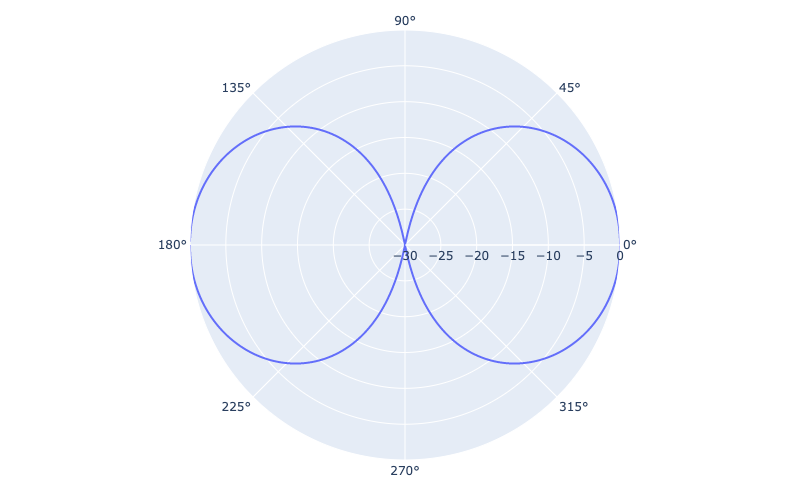
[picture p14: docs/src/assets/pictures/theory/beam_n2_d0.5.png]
  
  \caption{Phased array distribution characteristics ($d = \cfrac{1}{2}\lambda$, 2 emitters)}\label{fig:theory:beam:n2_d.5}
\end{figure}
\clearpage
\subsection{Distance between Emitters}

The beamforming characteristics can easily be influenced by the distance between the emitters, hence any changes in the phaseshift.
%As shown in equation \ref{eq:theory:beam:single_phaseshift} the phaseshift between two emitters depends on the distance between them. Therefore the beamforming characteristics can be easily influenced by this.
The ideal distance is half of the wavelength of the transmitted signal. With this spacing the two waves cancel each other out at exactly $90^\circ$ as shown in figure \ref{fig:theory:beam:n2_d.5}.\p
%
Figures \ref{fig:theory:beam:d} and \ref{fig:theory:beam:n2_d.5} show the beamforming characteristics of a phased array with $2$ emitters and a distance of $\cfrac{1}{4}\lambda$, $\cfrac{1}{2}\lambda$, $\lambda$, and $2\lambda$. The graph shows that using a smaller distance than $\frac{1}{2} \lambda$ makes the beamforming effect slowly disappear while a higher distance introduces side lobes at $\pm 90^\circ$. If the distance is further increased, the side lobes split up and new ones emerge at $\pm 90^\circ$.
%
\begin{figure}[ht]
  \begin{subfigure}[b]{0.32\textwidth}
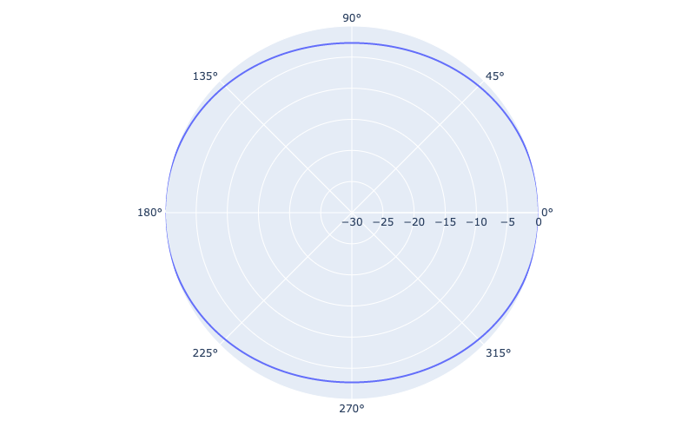
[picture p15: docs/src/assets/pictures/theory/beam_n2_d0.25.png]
    
    \caption{$d = \cfrac{1}{4}\lambda$}
    \label{fig:theory:beam:d.25}
  \end{subfigure}
  \hfill
  \begin{subfigure}[b]{0.32\textwidth}
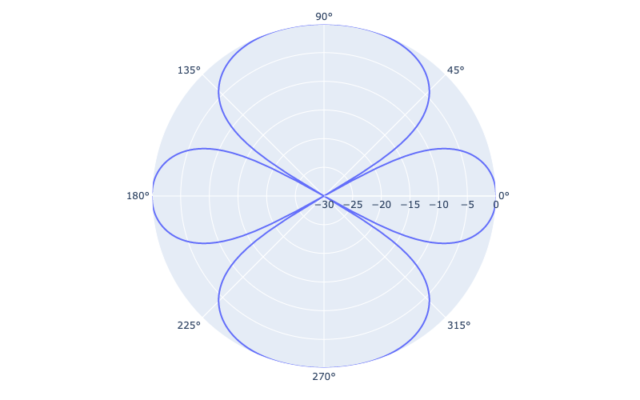
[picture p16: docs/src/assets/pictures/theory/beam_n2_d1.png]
    
    \caption{$d = \lambda$}
    \label{fig:theory:beam:d1}
  \end{subfigure}
  \hfill
  \begin{subfigure}[b]{0.32\textwidth}
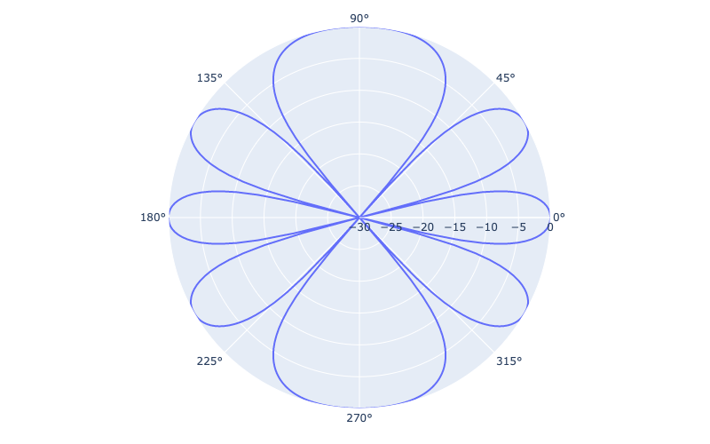
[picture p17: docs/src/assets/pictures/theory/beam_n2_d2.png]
    
    \caption{$d = 2\lambda$}
    \label{fig:theory:beam:d2}
  \end{subfigure}
  \caption{Beamforming characteristics depending on the distance between emitters}
  \label{fig:theory:beam:d}
\end{figure}
%
\subsection{Number of Emitters}

Figure \ref{fig:theory:beam:num} shows the beamforming characteristics of a phased array with $2$, $5$ and $20$ emitters. The distance between the emitters is set to $\frac{1}{2} \lambda$. From the graphs it can be observed, that by increasing the number of emitters the generated beam gets narrower. However a higher number of emitters also introduces new side lobes with a smaller amplitude. The amplitude of the side lobes decreases the larger the number of emitters gets.
%
\begin{figure}[ht]
  \begin{subfigure}[b]{0.32\textwidth}
    
    \caption{2 emitters}
    \label{fig:theory:beam:num_2}
  \end{subfigure}
  \hfill
  \begin{subfigure}[b]{0.32\textwidth}
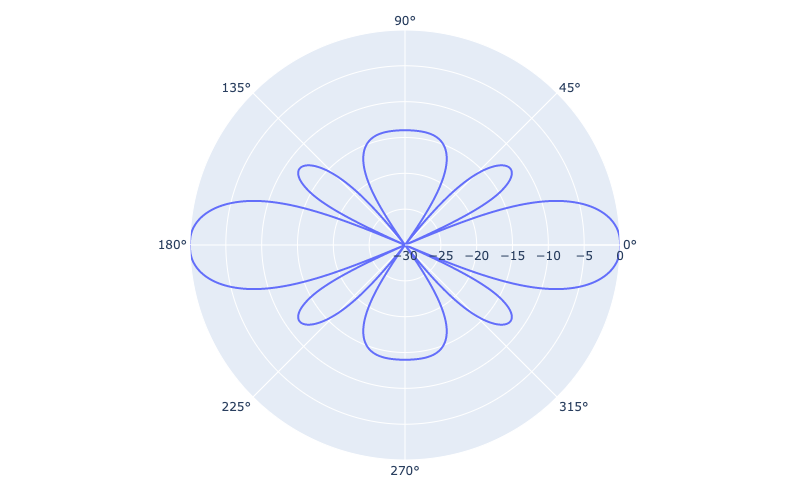
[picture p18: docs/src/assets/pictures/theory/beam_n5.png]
    
    \caption{5 emitters}
    \label{fig:theory:beam:num_5}
  \end{subfigure}
  \hfill
  \begin{subfigure}[b]{0.32\textwidth}
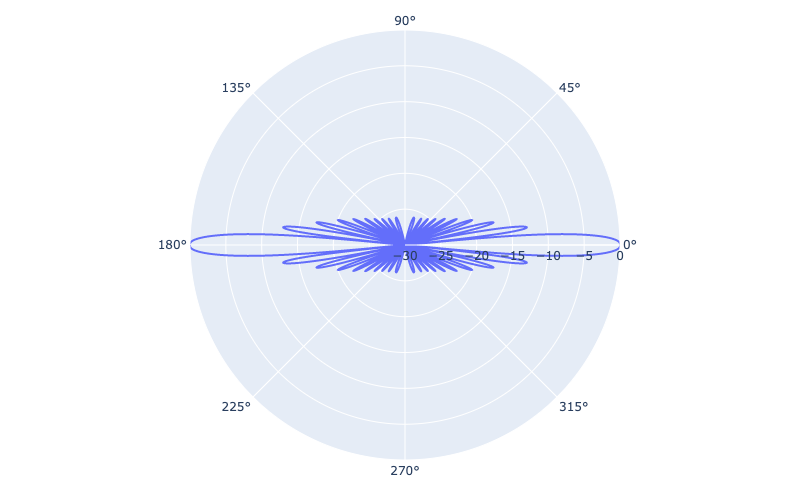
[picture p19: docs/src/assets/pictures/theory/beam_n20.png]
    
    \caption{20 emitters}
    \label{fig:theory:beam:num_20}
  \end{subfigure}
  \caption{Beamforming characteristics depending on the number of emitters}
  \label{fig:theory:beam:num}
\end{figure}
%
\subsection{Dispersion Characteristics of Emitters}
For the calculations above, the emitters are assumed to be isotropic radiators. In a real world scenario a speaker has some form of direction characteristic. The exact behaviour is highly dependent of the signal frequency. A higher frequency usually leads to more directivity.\cite{cox_frequency-dependent_2007}\cite{hill_frequency_2014}\p
%
%Figure \dots shows the dispersion characteristics of the ultrasonic transducer used in this project. This behavior can be modelled into equation \ref{eq:theory:beam:sig} as follows:
%
%\begin{align}
%  s_e(t, \varphi, n) &= \dots
%\end{align}
%
%The resulting characteristics of the phased array compared to the result with isotropic radiators are shown in figure \dots. It can be observed, that \dots

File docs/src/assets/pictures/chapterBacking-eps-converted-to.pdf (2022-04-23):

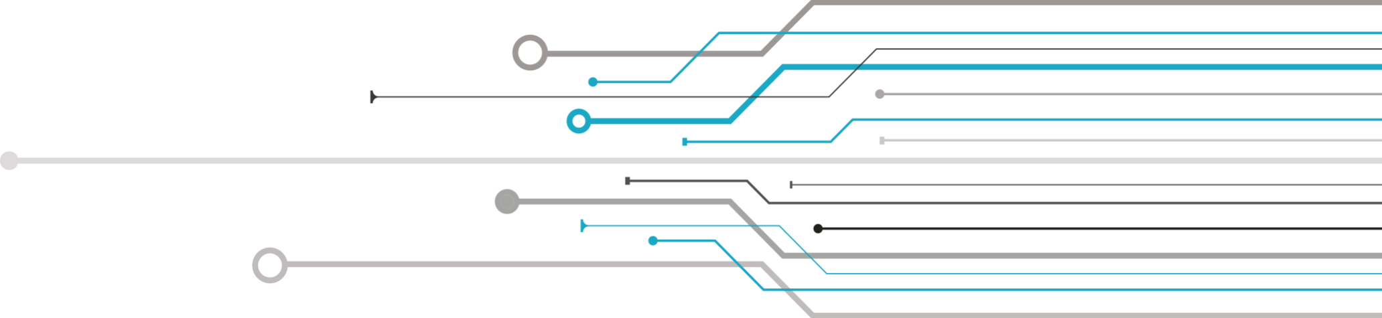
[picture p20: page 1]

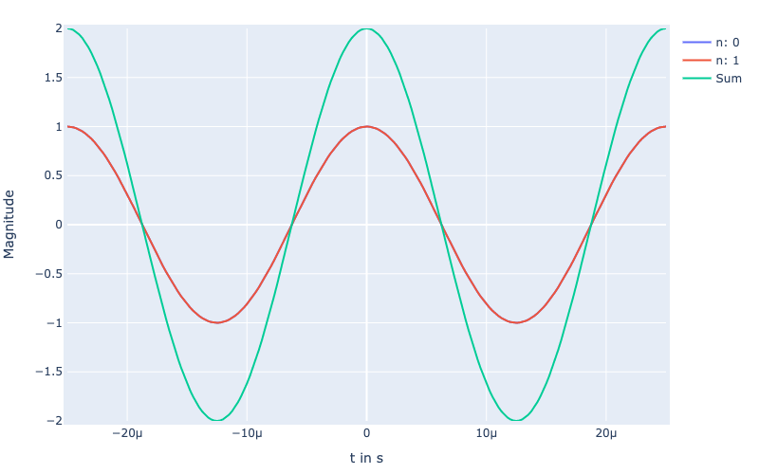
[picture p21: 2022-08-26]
docs/src/assets/pictures/theory/beam_time_n2_0deg.png

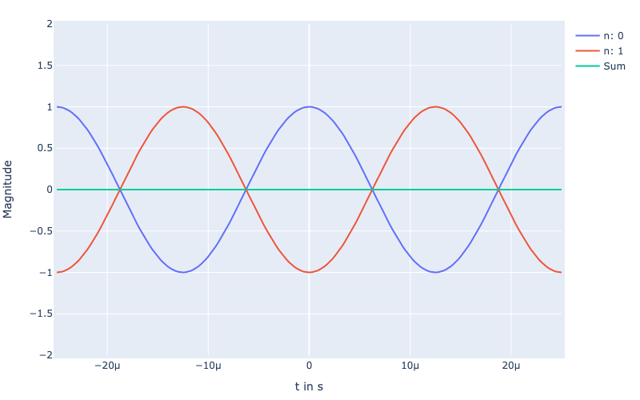
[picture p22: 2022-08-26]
docs/src/assets/pictures/theory/beam_time_n2_90deg.png

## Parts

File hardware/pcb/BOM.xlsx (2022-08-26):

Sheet: speaker
Id | Designator | Package | Quantity | Quantity x7 | Designation | Supplier | notes | Basket
1 | R9,R8 | R_0805_2012Metric_Pad1.20x1.40mm_HandSolder | 2 | 16.8 | 15k |  |  | x
2 | R7 | R_0805_2012Metric_Pad1.20x1.40mm_HandSolder | 1 | 8.4 | 100k |  |  | x
3 | R6,R5 | R_0805_2012Metric_Pad1.20x1.40mm_HandSolder | 2 | 16.8 | 1.5k |  | I2C Pull-Up | x
4 | R4,R3,R2 | R_0805_2012Metric_Pad1.20x1.40mm_HandSolder | 3 | 25.2 | 10k |  |  | x
5 | R1 | R_0805_2012Metric_Pad1.20x1.40mm_HandSolder | 1 | 8.4 | 180k |  |  | x
6 | C11,C10,C8,C6,C4 | C_0805_2012Metric_Pad1.18x1.45mm_HandSolder | 5 | 42 | 100nF |  | 2 x Stützkondensator 5V, 1 x Stützkondensator 24V, 2x Hochpassfilter 24V (niedrige ESR) | x
7 | C9 | C_0805_2012Metric_Pad1.18x1.45mm_HandSolder | 1 | 8.4 | 82nF |  |  | x
8 | C7 | C_0805_2012Metric_Pad1.18x1.45mm_HandSolder | 1 | 8.4 | 470pF |  |  | x
9 | C5,C2 | C_1206_3216Metric_Pad1.33x1.80mm_HandSolder | 2 | 16.8 | 10uF |  | Stützkondensator 24V | x
10 | C3 | C_0805_2012Metric_Pad1.18x1.45mm_HandSolder | 1 | 8.4 | 10uF |  | Stützkondensator 5V | x
11 | C1 | C_1206_3216Metric_Pad1.33x1.80mm_HandSolder | 1 | 8.4 | 22uF |  |  | x
12 | C12,C13 | C_0805_2012Metric_Pad1.18x1.45mm_HandSolder | 2 | 16.8 | 1nF |  | Stützkondensator 24 V | x
13 | M15,M6,M7,M11,M12,M9,M19,M5,M1,M14,M8,M16,M13,M4,M3,M2,M10,M17,M18 | CUSP-T80-15-2400-TH | 19 | 159.6 | Ultrasonic_Transducer |  |  | 20x
14 | J5,J6,J2,J1,J3,J4 | JST_SH_BM02B-SRSS-TB_1x02-1MP_P1.00mm_Vertical | 6 | 50.4 | JST SH BM02B Connector |  | SMD JST connector für I2C | x
15 | U1 | LTC2631-Z | 1 | 8.4 |  | Mouser.at |  | x
16 | OP1 | SOT-23-5_HandSoldering | 1 | 8.4 | TL081HIDBVR | Mouser.at |  | x
17 | U2 | SOT-23-5_HandSoldering | 1 | 8.4 | LM2735XMF | Mouser.at |  | x
18 | J7 | JST_PH_B2B-PH-K_1x02_P2.00mm_Vertical | 1 | 8.4 | JST PH B2B Connector |  | THT JST connector for VCC | x
19 | L1 | L_Wuerth_5030_Handsolder | 1 | 8.4 | 10uH | Würth | WE-XHMI SMT Power Inductor (74439346100)
20 | D1 | D_SMB_Handsoldering | 1 | 8.4 | SSB44 | Mouser.at |  | x

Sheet: speaker_v2
Id | Designator | Package | Quantity | Quantity x7 | Designation | Basket | In Stock | On Supply
1 | D1 | D_SMB_Handsoldering | 1 | 8.4 | SSB44 |  | x | x
2 | C10 | C_1206_3216Metric_Pad1.33x1.80mm_HandSolder | 1 | 8.4 | 1uF | x |  | x
3 | M15,M6,M7,M11,M12,M9,M19,M5,M1,M14,M8,M16,M13,M4,M3,M2,M10,M17,M18 | CUSP-T80-15-2400-TH | 19 | 159.6 | Ultrasonic_Transducer | x |  | x
4 | TP3,TP2,TP1 | TestPoint_Keystone_5000-5004_Miniature | 3 | 25.2 | TestPoint | - | -
5 | C2,C14,C5, C3 | C_1206_3216Metric_Pad1.33x1.80mm_HandSolder | 4 | 33.6 | 10uF | x 16 | ? 16 | x
6 | R2 | R_0805_2012Metric_Pad1.20x1.40mm_HandSolder | 1 | 8.4 | 10k |  | x
7 | J5,J1,J6,J2,J3,J4 | SPI_Conn_SMD | 6 | 50.4 | Conn_01x03 |  | x
8 | R4 | R_0805_2012Metric_Pad1.20x1.40mm_HandSolder | 1 | 8.4 | 5k |  | x
9 | J7 | PinHeader_1x02_P2.54mm_Vertical_SMD_Pin1Left | 1 | 8.4 | Conn_01x02 |  | x
10 | C9 | C_0805_2012Metric_Pad1.18x1.45mm_HandSolder | 1 | 8.4 | 10nF | x | ? 8 | x
11 | R8,R10,R7,R11,R9 | R_0805_2012Metric_Pad1.20x1.40mm_HandSolder | 5 | 42 | 100k |  | x
12 | R3 | R_0805_2012Metric_Pad1.20x1.40mm_HandSolder | 1 | 8.4 | 15k |  | x
13 | Q2 | SOT-23 | 1 | 8.4 | BC857
14 | C4,C6,C15,C11 | C_0805_2012Metric_Pad1.18x1.45mm_HandSolder | 4 | 33.6 | 100nF | x | ? 42 | x
15 | C3 | C_0805_2012Metric_Pad1.18x1.45mm_HandSolder | 1 | 8.4 | 10uF |  | ? 8
16 | C1 | C_1206_3216Metric_Pad1.33x1.80mm_HandSolder | 1 | 8.4 | 22uF | x 10 | ? 8 | x
17 | OP1 | SOT-23-5_HandSoldering | 1 | 8.4 | ADA4622-1 |  | x | x
18 | C12,C13 | C_0805_2012Metric_Pad1.18x1.45mm_HandSolder | 2 | 16.8 | 1nF |  | ? 16 | x
19 | H1,H2,H4,H3 | MountingHole_2.2mm_M2_DIN965_Pad_TopBottom | 4 | 33.6 | MountingHole_Pad | - | -
20 | R1 | R_0805_2012Metric_Pad1.20x1.40mm_HandSolder | 1 | 8.4 | 180k |  | x
21 | U2 | SOT-23-5_HandSoldering | 1 | 8.4 | LM2735XMF |  | x | x
22 | C8 | C_0805_2012Metric_Pad1.18x1.45mm_HandSolder | 1 | 8.4 | 1.5nF | x |  | x
23 | Q1 | SOT-23 | 1 | 8.4 | BC847 |  | x (Läßer)
24 | L1 | L_Wuerth_5030_Handsolder | 1 | 8.4 | 10uH |  | x
25 | U1 | SOT-23-8_Handsoldering | 1 | 8.4 | LTC2640-Z | x |  | x
26 | C7 | C_0805_2012Metric_Pad1.18x1.45mm_HandSolder | 1 | 8.4 | 470pF |  | ? 8 | x

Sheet: vcc distributor
id | designator | package | quantity | designation | supplier | note | Basket
1 | J3,J2,J6,J4,J8,J7,J5 | JST_PH_B2B-PH-K_1x02_P2.00mm_Vertical | 7 | JST PH B2B Connector |  | THT JST connector for VCC distribution to all speakers | x
2 | J1 | TerminalBlock_Phoenix_MKDS-1,5-2_1x02_P5.00mm_Horizontal | 1 | Screw_Terminal_01x02 |  | THT connector for VCC in

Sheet: mount
id | designator | package | quantity | designation | supplier | note
1 | S1,S2 | - | 2 |  |  | Servo Motor
2 | - | - | 2 |  |  | Servo Rod with ball joint (ca. 60mm)

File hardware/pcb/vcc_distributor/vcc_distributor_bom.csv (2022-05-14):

Id | Designator | Package | Quantity | Designation | Supplier and ref
1 | J3,J2,J6,J4,J8,J7,J5 | JST_PH_B2B-PH-K_1x02_P2.00mm_Vertical | 7 | Conn_01x02
2 | J1 | TerminalBlock_Phoenix_MKDS-1,5-2_1x02_P5.00mm_Horizontal | 1 | Screw_Terminal_01x02

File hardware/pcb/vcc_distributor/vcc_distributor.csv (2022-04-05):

ID | Bezeichner | Gehäuse | Stückzahl | Bezeichnung | Anbieter und Referenz
1 | J3,J2,J6,J4,J8,J7,J5 | JST_PH_B2B-PH-K_1x02_P2.00mm_Vertical | 7 | Conn_01x02
2 | J1 | TerminalBlock_Phoenix_MKDS-1,5-2_1x02_P5.00mm_Horizontal | 1 | Screw_Terminal_01x02

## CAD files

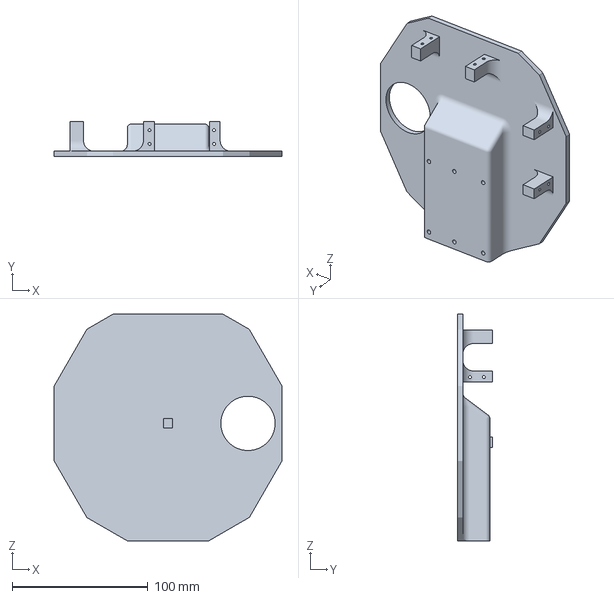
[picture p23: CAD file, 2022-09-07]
hardware/models/base.3mf
168.2 x 26.0 x 167.2 mm

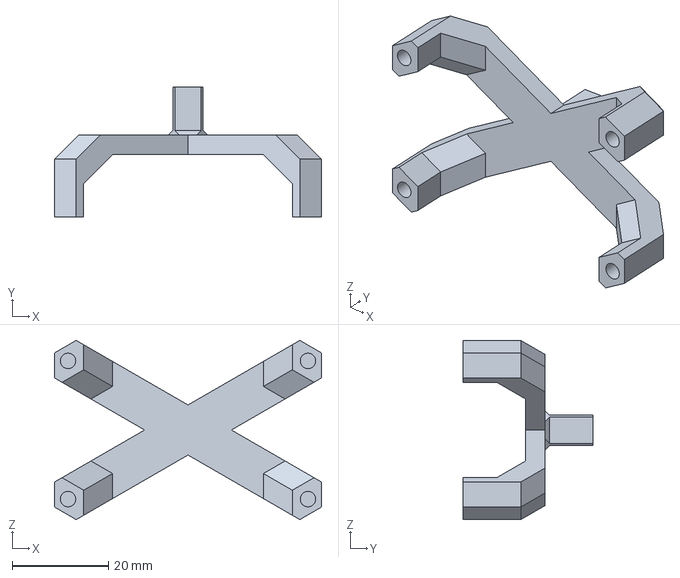
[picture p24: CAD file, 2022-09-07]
hardware/models/pcb_mount.3mf
55.4 x 27.0 x 37.2 mm

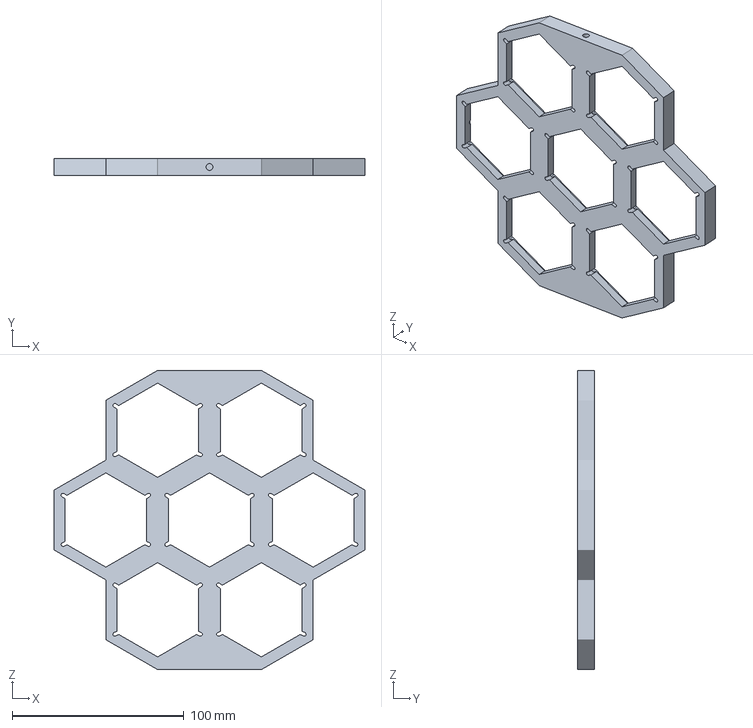
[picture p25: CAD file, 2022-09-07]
hardware/models/pcb_plate.3mf
180.8 x 10.0 x 174.0 mm

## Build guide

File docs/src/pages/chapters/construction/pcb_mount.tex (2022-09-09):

\section{Integration}

%\begin{enumerate}
%  \item Requirements
%  \subitem power cable passthrough
%  \subitem Raspberry Pi Mount
%\end{enumerate}

As described in section \secref{sec:concept} the speaker consist of seven modules. Therefore a frame is needed to mount them all into place. In addition a tripod mount should be added. In order to integrate the tilting mechanism the construction is divided into two parts: The frame, which mounts the PCB and the base, holding the servos and the control board (raspberry pi, microcontroller or similar). All parts are printed with a 3D printer. The finished speaker is shown in figure \ref{fig:const:int:const}.
%
\begin{figure}[ht]
  \begin{subfigure}[b]{0.49\textwidth}
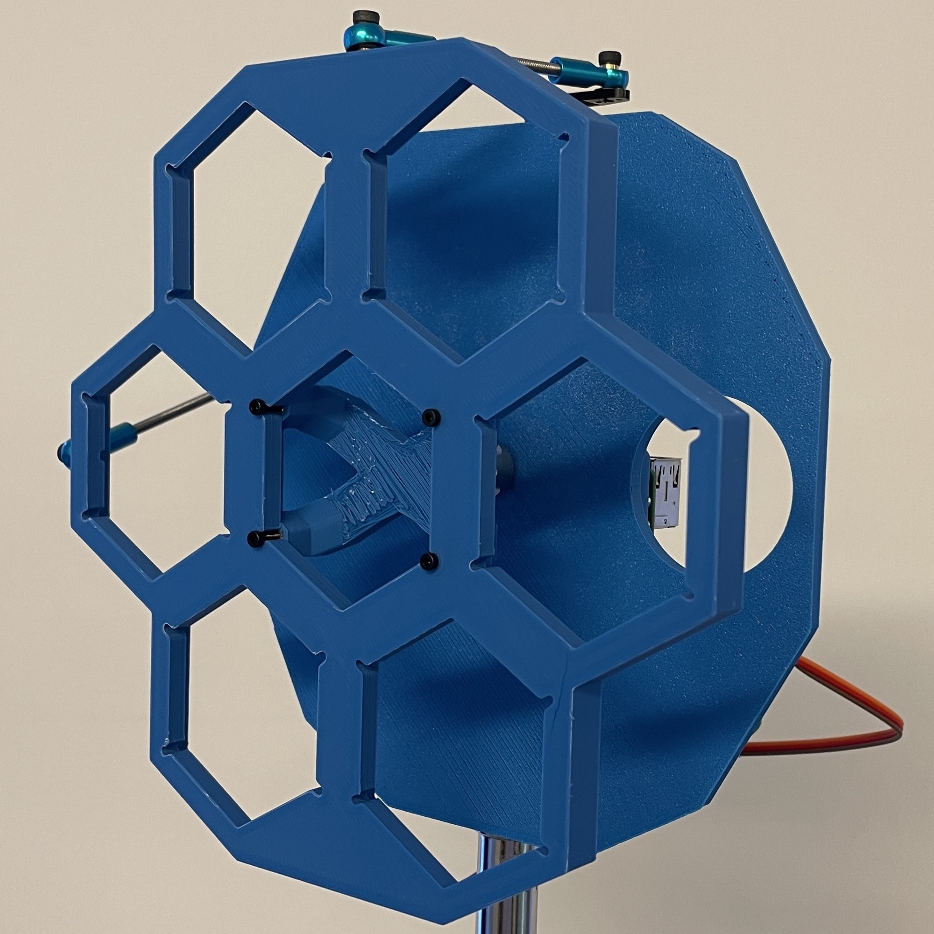
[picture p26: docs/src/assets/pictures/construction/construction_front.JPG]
    
    \caption{Front view}
    \label{fig:const:int:const_front}
  \end{subfigure}
  \hfill
  \begin{subfigure}[b]{0.49\textwidth}
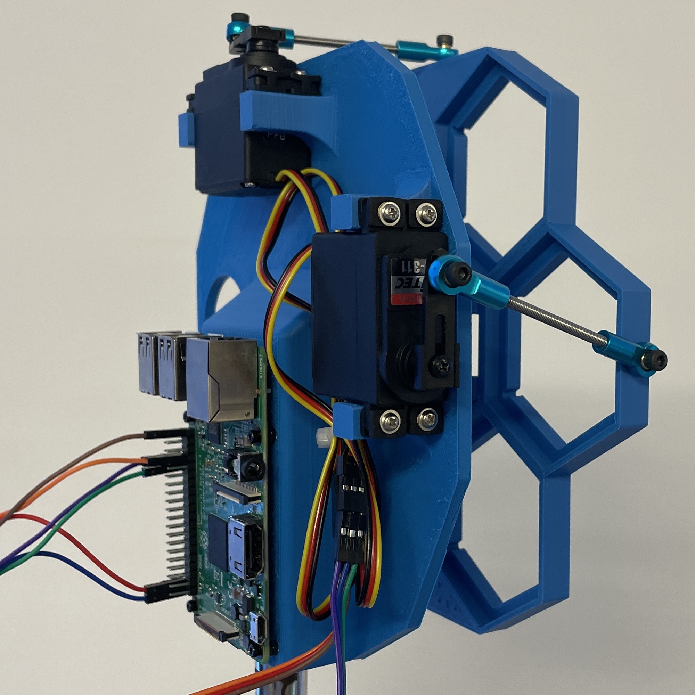
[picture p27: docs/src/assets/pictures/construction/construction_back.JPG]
    
    \caption{Back view}
    \label{fig:const:int:const_back}
  \end{subfigure}
  \caption{Complete speaker}
  \label{fig:const:int:const}
\end{figure}
%
\subsubsection*{Tilting Mechanism}

The tilting mechanism is realized using a cardan joint (figure \ref{fig:const:int:cardan_joint}) as joint (\textbf{A}). The rotation of \textbf{F} is created with servos. The shafts \textbf{D} and \textbf{E} are built with a servo arm and threaded rod connected with ball joints (figure \ref{fig:const:int:shaft}). The whole construction is displayed in figure \ref{fig:const:int:const}
%
\begin{figure}[ht]
  \begin{subfigure}[b]{0.174\textwidth}
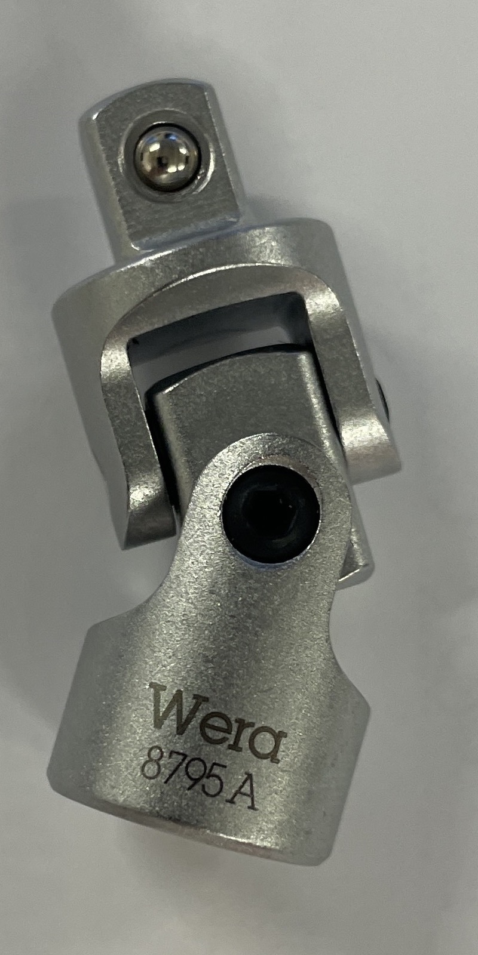
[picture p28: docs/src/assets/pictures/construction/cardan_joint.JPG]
    
    \caption{Cardan Joint}
    \label{fig:const:int:cardan_joint}
  \end{subfigure}
  \hfill
  \begin{subfigure}[b]{0.80\textwidth}
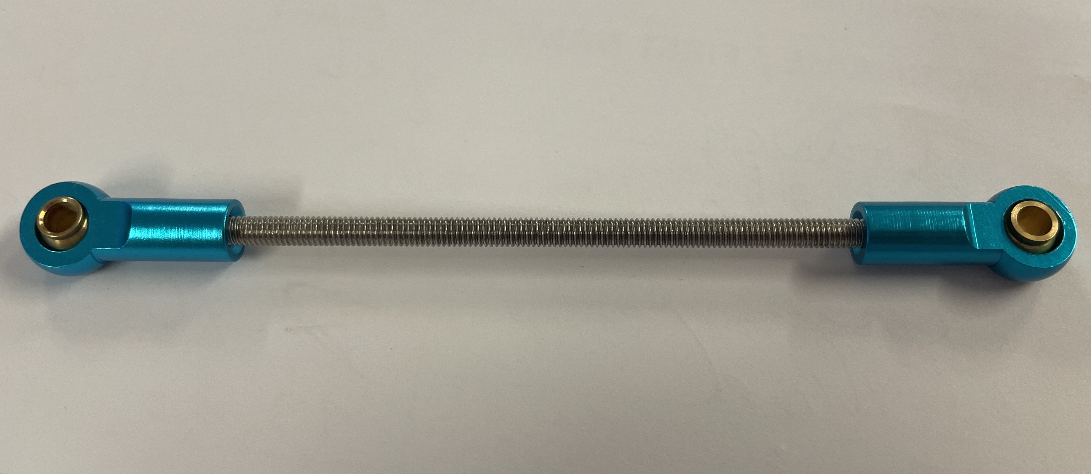
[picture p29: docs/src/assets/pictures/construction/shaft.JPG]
    
    \caption{Shaft}
    \label{fig:const:int:shaft}
  \end{subfigure}
  \caption{Components for the tilting mechanism}
  \label{fig:const:int:tiltin_components}
\end{figure}
%
\subsubsection*{PCB Mount}
%
One speaker module is mounted using a hexagon frame (figure \ref{fig:const:int:mount}). The PCB is bolted to the frame. To mount all modules, seven of those frames are combined to one model (figure \ref{fig:const:int:const}). Threaded holes on the top and the left side provide an option to attach the ball joints for the tilting mechanism. The cardan joint is connected using the model shown in figure \ref{fig:const:int:mount_back}. It is screwed to the back of the center PCB.
%
\begin{figure}[ht]
  \begin{subfigure}[b]{0.49\textwidth}
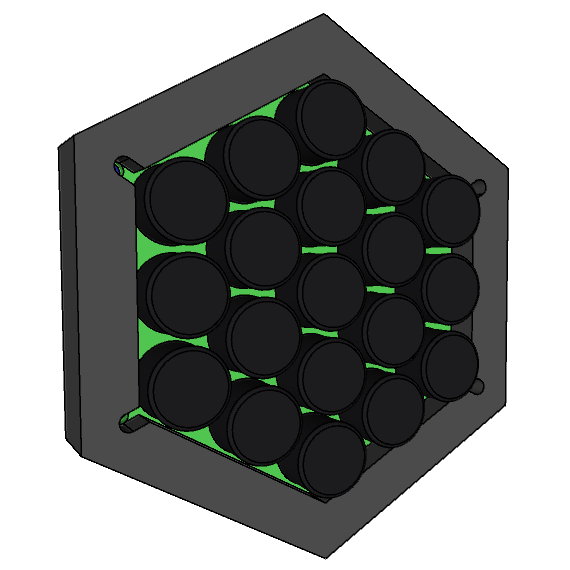
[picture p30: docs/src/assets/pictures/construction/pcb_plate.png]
    
    \caption{Front view}
    \label{fig:const:int:mount_front}
  \end{subfigure}
  \hfill
  \begin{subfigure}[b]{0.49\textwidth}
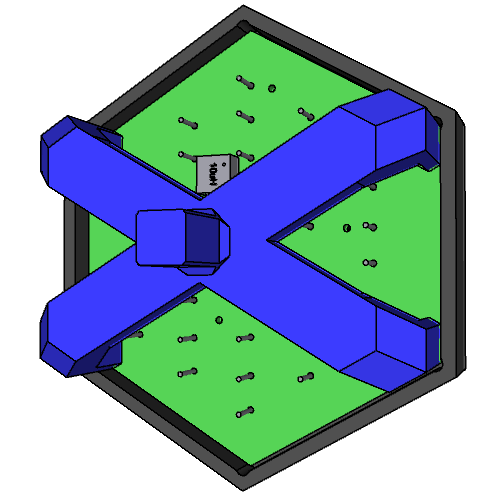
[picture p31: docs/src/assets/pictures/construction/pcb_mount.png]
    
    \caption{Back view}
    \label{fig:const:int:mount_back}
  \end{subfigure}
  \caption{PCB mount model with cardan joint connector}
  \label{fig:const:int:mount}
\end{figure}
%
\subsubsection*{Base}

The base mimics the form of the PCB mount. A squared hole in the center allows the connection of the cardan joint. Servos are mounted to the back of the base at similar positions as the ball joints on the PCB mount. A thread on the bottom of the model will allow the speaker to be mounted on a tripod. The design of the base plate is shown in figure \ref{fig:const:int:base}.
%
\begin{figure}[ht]
  \centering
  \begin{subfigure}{0.59\textwidth}
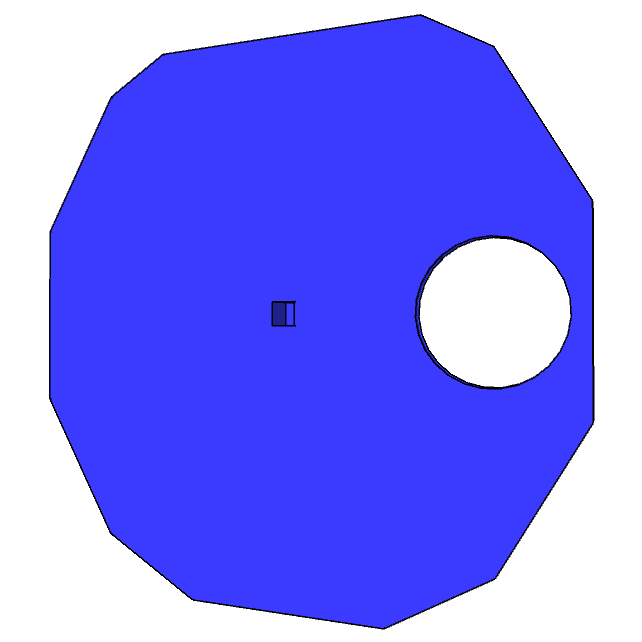
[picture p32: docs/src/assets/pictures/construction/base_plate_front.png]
    
    \caption{Front view}
    \label{fig:const:int:base_front}
  \end{subfigure}
  \\
  \begin{subfigure}{0.6\textwidth}
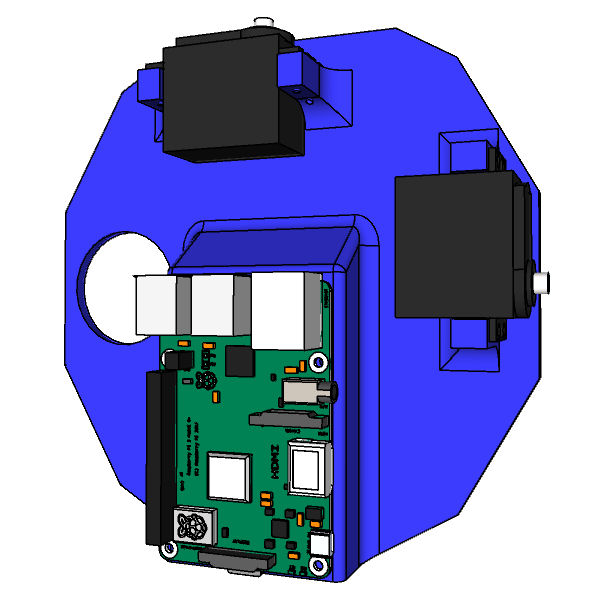
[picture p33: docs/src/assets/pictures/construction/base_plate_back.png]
    
    \caption{Back view}
    \label{fig:const:int:base_back}
  \end{subfigure}
  \caption{Base plate model with servo motors and Respberry Pi}
  \label{fig:const:int:base}
\end{figure}

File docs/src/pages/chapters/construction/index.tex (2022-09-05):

\chapter{Speaker Construction}
%
As described in section \secref{sec:concept} the direction of the speaker is altered using a mechanical construction, which is explained in the following section.
%
\input{src/pages/chapters/construction/tilting_mechanism.tex}
\input{src/pages/chapters/construction/pcb_mount.tex}

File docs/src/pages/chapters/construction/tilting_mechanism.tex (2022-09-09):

\section{Tilting Mechanism}\label{sec:const:tilt}

%\begin{enumerate}
%  \item Requirements
%  \subitem Angular range
%\end{enumerate}

%\subsubsection*{Concept}

The tilting mechanism allows the PCBs to tilt around two axis. For developing the concept the PCBs are displayed as a plane. Figure \ref{fig:const:tilt:mech} and \ref{fig:const:tilt:math} show the front and top view of the tilting mechanism for one axis.
%
\begin{figure}[ht]
  \begin{subfigure}[b]{0.49\textwidth}
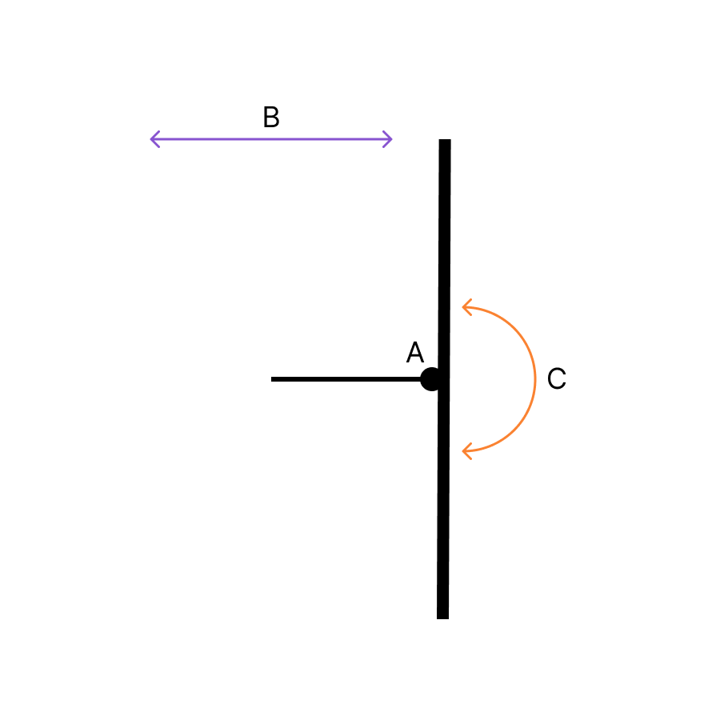
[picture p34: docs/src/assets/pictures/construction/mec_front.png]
    
    \caption{Front view}
    \label{fig:const:tilt:mech_front}
  \end{subfigure}
  \hfill
  \begin{subfigure}[b]{0.49\textwidth}
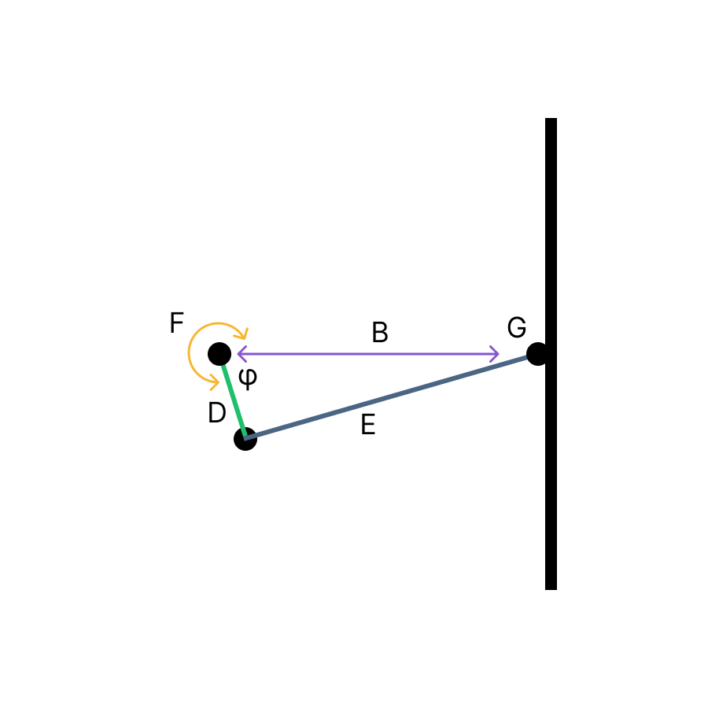
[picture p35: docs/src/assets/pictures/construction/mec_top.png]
    
    \caption{Top view}
    \label{fig:const:tilt:mech_top}
  \end{subfigure}
  \caption{Mechanical sketch of the tilting mechanism}
  \label{fig:const:tilt:mech}
\end{figure}
\newpage\noindent
The PCBs are held in place by a joint in the center of the plane (\textbf{A}). When the top of the PCBs is moved forwards or backwards (\textbf{B}), the plane rotates. The forward and backward movement can be created by connecting to shafts (\textbf{D} and \textbf{E}) with a joint. The base of \textbf{D} (\textbf{F}) is fixed while the end of \textbf{E} is connected to the top of the plane. This creates the triangle \textbf{D} - \textbf{E} - \textbf{B}. When the base of \textbf{D} is now rotated the shape of the triangle is changed, increasing or decreasing the length of \textbf{B}.
The rotation around two axis can be achieved by adding a second \textbf{D} - \textbf{E} - \textbf{B} triangle to the left or right side of the plane.
%
\begin{figure}
  \begin{subfigure}[b]{0.49\textwidth}
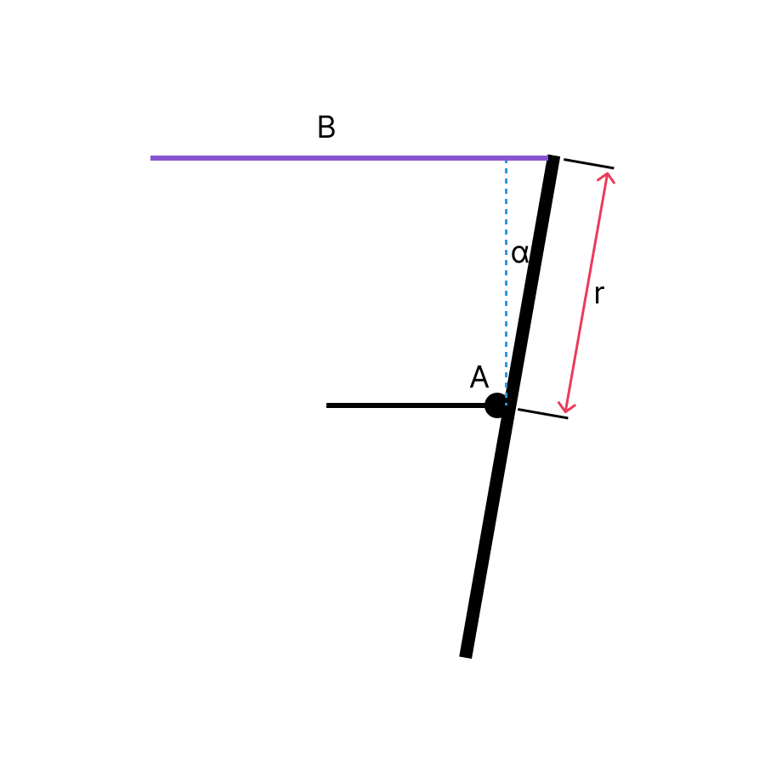
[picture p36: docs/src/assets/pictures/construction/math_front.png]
    
    \caption{Front view}
    \label{fig:const:tilt:math_front}
  \end{subfigure}
  \hfill
  \begin{subfigure}[b]{0.49\textwidth}
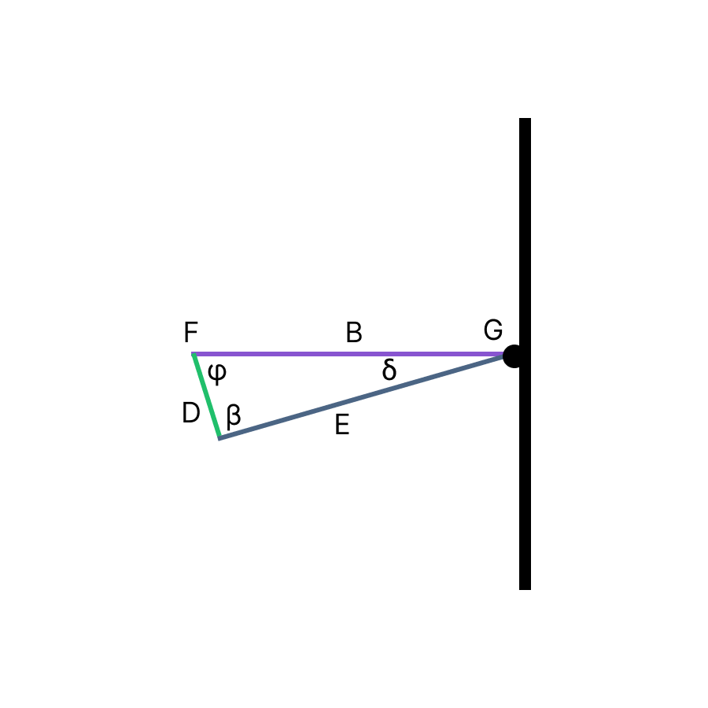
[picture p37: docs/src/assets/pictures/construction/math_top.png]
    
    \caption{Top view}
    \label{fig:const:tilt:math_top}
  \end{subfigure}
  \caption{Mathematical sketch of the tilting mechanism}
  \label{fig:const:tilt:math}
\end{figure}
\p
Using this setup the tilting angle $\alpha$ is controlled using the angle $\varphi$. This can be described mathematically as follows. First $\varphi$ is defined with the length of \textbf{B} using the law of cosines.
%
\begin{align}
  E^2     &= D^2 + B^2 - 2DE \cdot \cos \varphi \pmath
  \varphi &= \arccos \left( \frac{D^2 + B^2 - E^2}{2DE} \right) \label{eq:const:tilt:phi_semi}
\end{align}
%
Next $\alpha$ is used to derive \textbf{B}. The result is inserted into equation \ref{eq:const:tilt:phi_semi}.
%
\begin{align}
  \sin \alpha &= \frac{B - B_0}{r}\pmath
  B           &= \sin (\alpha) \cdot r + B_0\pmath
  \mathrm{with~} B_0 &= B(\alpha = 0^\circ, \varphi = 90^\circ) = \sqrt{D^2 + E^2}\pmath
  B           &= \sin (\alpha) \cdot r + \sqrt{D^2 + E^2}
\end{align}
%
\textbf{B$_0$} is the length of \textbf{B} when $\alpha = 0^\circ$. To achieve symmetric movement $\alpha$ is defined to be $0^\circ$ when $\varphi = 90^\circ$. This results in the following equation for $\varphi$:
%
\begin{align}
  \varphi &= \arccos \left( \frac{D^2 + (\sin (\alpha) \cdot r + \sqrt{D^2 + E^2})^2 - E^2}{2DE} \right)
\end{align}
%
It should be noted that this solution is only an approximation. As shown in figure \ref{fig:const:tilt:math} even though the plane rotates, \textbf{B} remains in a straight line. In reality the plane would rotate on a circular path which would change the angle of \textbf{B} (in the front view). With it the actual length of \textbf{B} would change depending on the angle $\alpha$. However during testing on the real speaker the error of the calculation was to small to be noticeable.

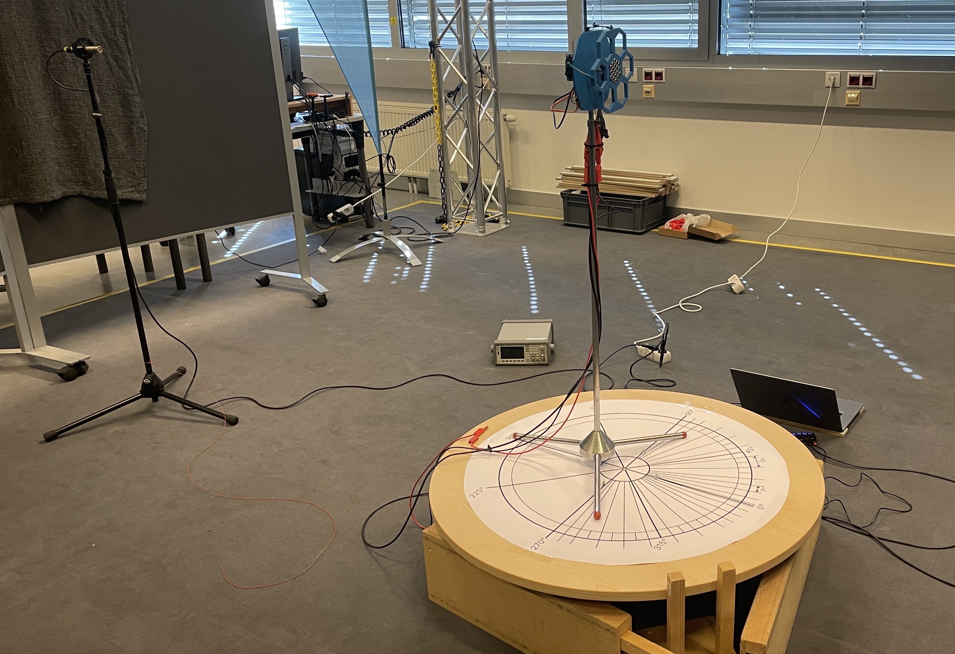
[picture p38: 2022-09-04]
docs/src/assets/pictures/measurements/beamforming_meas_setup_v2.JPG

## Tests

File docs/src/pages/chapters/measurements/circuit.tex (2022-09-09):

\section{Circuit}

\subsection{Power Supply}

Figure \ref{fig:meas:circ:power} shows the output of the boost converter. The measurements show that the output voltage reaches up to $23.7\,V$. Besides that voltage spikes of $239\,mV$ at the switching frequency where measured. This means the boost converter provides a voltage wich is high and stable enough to supply the circuit.
%
\begin{figure}
  \centering
  \begin{subfigure}[b]{0.8\textwidth}
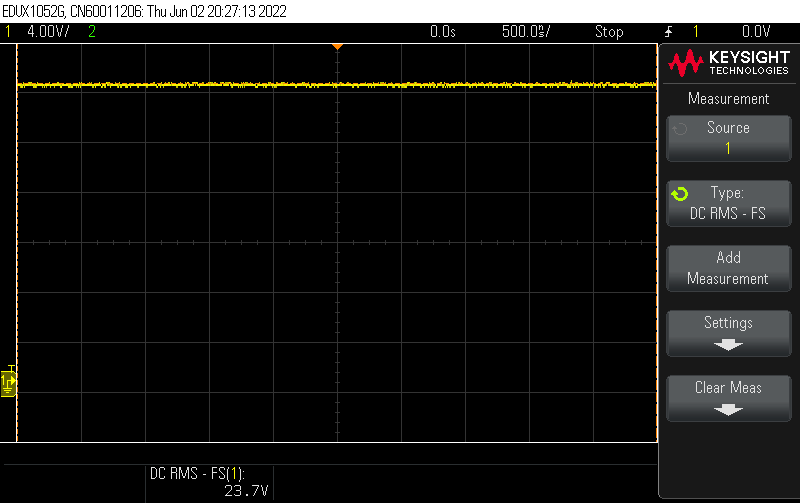
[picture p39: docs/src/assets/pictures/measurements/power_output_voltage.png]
    
    \caption{Output voltage}
    \label{fig:meas:circ:power_out}
  \end{subfigure}
  \hfill
  \begin{subfigure}[b]{0.8\textwidth}
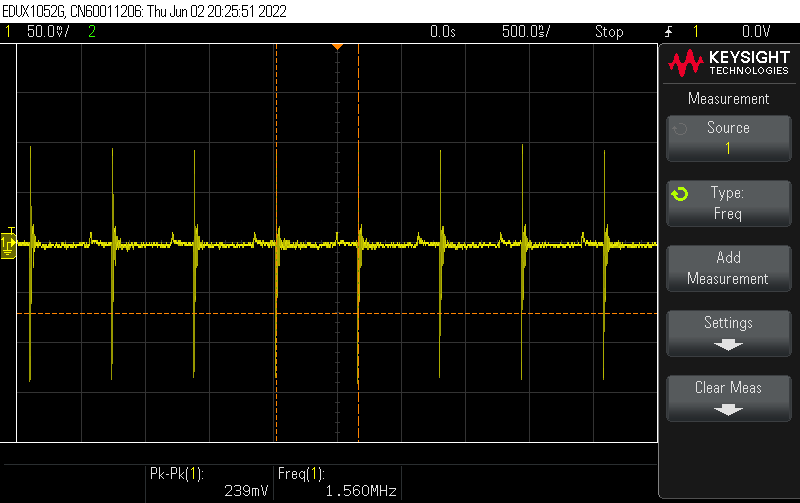
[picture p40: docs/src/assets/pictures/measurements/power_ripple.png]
    
    \caption{Ripple}
    \label{fig:meas:circ:power_ripple}
  \end{subfigure}
  \caption{Power supply output}
  \label{fig:meas:circ:power}
\end{figure}

\subsection{Amplifier Circuit}

The frequency response of the amplifier circuit is shown in figure \ref{fig:meas:circ:amp_bode}. It shows the amplification of $V=4$ for frequencies above $5\,kHz$ as intended. Additionally, the trend shows an amplification of $0\,dB$ for low frequencies which is necessary because of the single supply design.
%
\begin{figure}
  \centering
  
  \caption{Frequency response of the amplifier circuit}\label{fig:meas:circ:amp_bode}
\end{figure}
\p
Figures \ref{fig:meas:circ:amp_sin} shows a $40\,kHz$ sine wave amplified by the circuit with and without a load. Both measurements display a clean sine wave.
%
\begin{figure}
  \centering
  \begin{subfigure}[b]{0.8\textwidth}
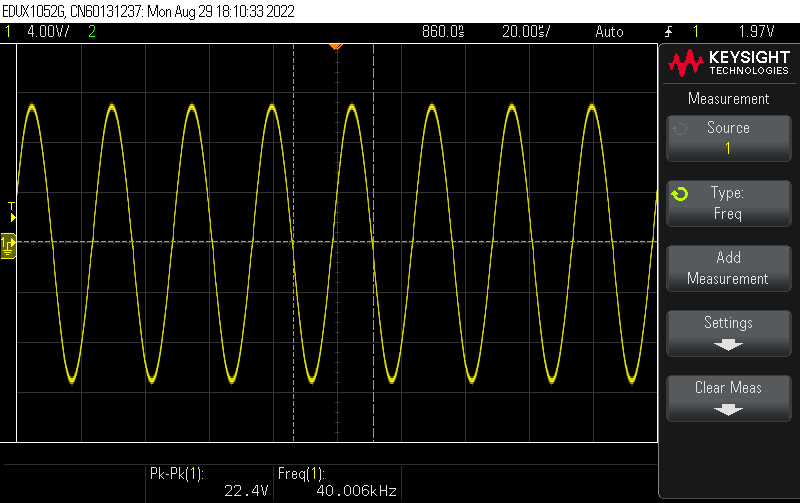
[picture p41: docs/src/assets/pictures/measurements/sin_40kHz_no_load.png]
    
    \caption{Without load}
    \label{fig:meas:circ:amp_sin_nol}
  \end{subfigure}
  \hfill
  \begin{subfigure}[b]{0.8\textwidth}
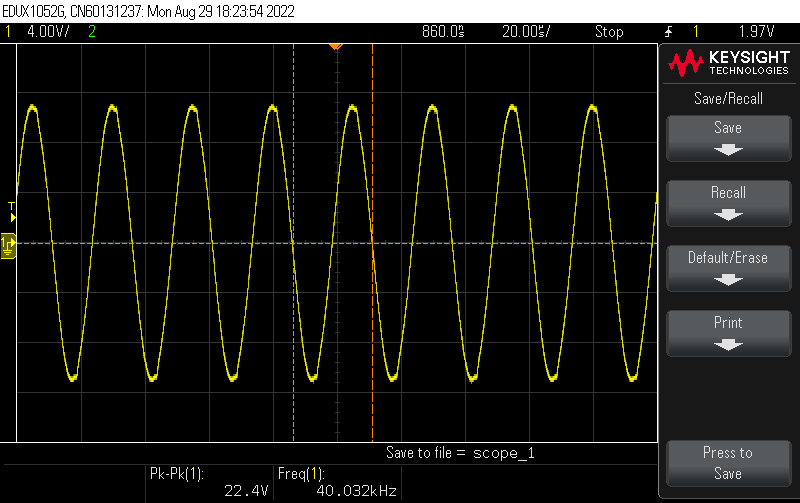
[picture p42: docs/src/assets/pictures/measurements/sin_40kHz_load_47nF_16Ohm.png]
    
    \caption{With load ($19$ ultrasonic transducers in parallel)}
    \label{fig:meas:circ:amp_sin_l}
  \end{subfigure}
  \caption{Amplification of a sine wave}
  \label{fig:meas:circ:amp_sin}
\end{figure}

\subsection{DAC}\label{sec:meas:circuit:dac}

During the writing of this thesis this component turned out to not work properly. As mentioned in the Datasheet the DAC takes the signal structure shown in Figure \ref{fig:meas:circ:dac_spi}. When the 4 config bits are set to $0011$ the output of the DAC is updated with the new value. The DAC also supports a power down mode by sending $0100$. The power down can be recognized by observing the output of the reference voltage. In power down mode the pin is set to high impedance and slowly falls to $0\,V$.\cite{linear_technology_ltc2640_2017}
%
\begin{figure}
  \centering
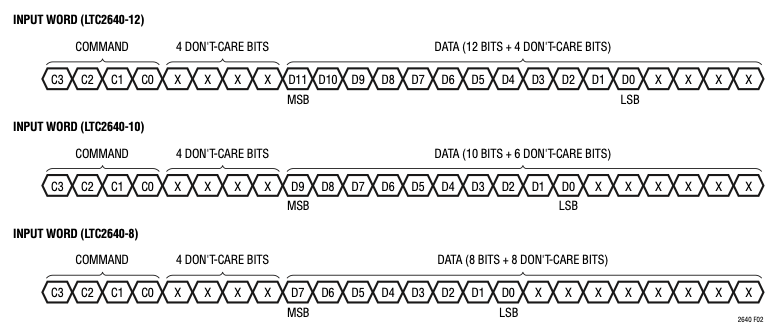
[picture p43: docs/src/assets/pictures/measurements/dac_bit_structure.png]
  
  \caption{LTC2640 SPI signal structure\cite{linear_technology_ltc2640_2017}}\label{fig:meas:circ:dac_spi}
\end{figure}
\p
While trying different values for the DAC it was observed, that the output voltage as well as the reference voltage became zero for some values. When sending the next value the DAC usually turned back on again. An analysis of the input and output signals during this process can be observed in Figure \ref{fig:meas:circ:dac_power_down}.\p
The picture shows the digital signal which has the config set to $0011$ as it should be. Despite this the reference voltage (blue) becomes zero and the DAC powers down after reading the config bits. Neither the reason nor a solution for this problem could be found.
%
\begin{figure}
  \centering
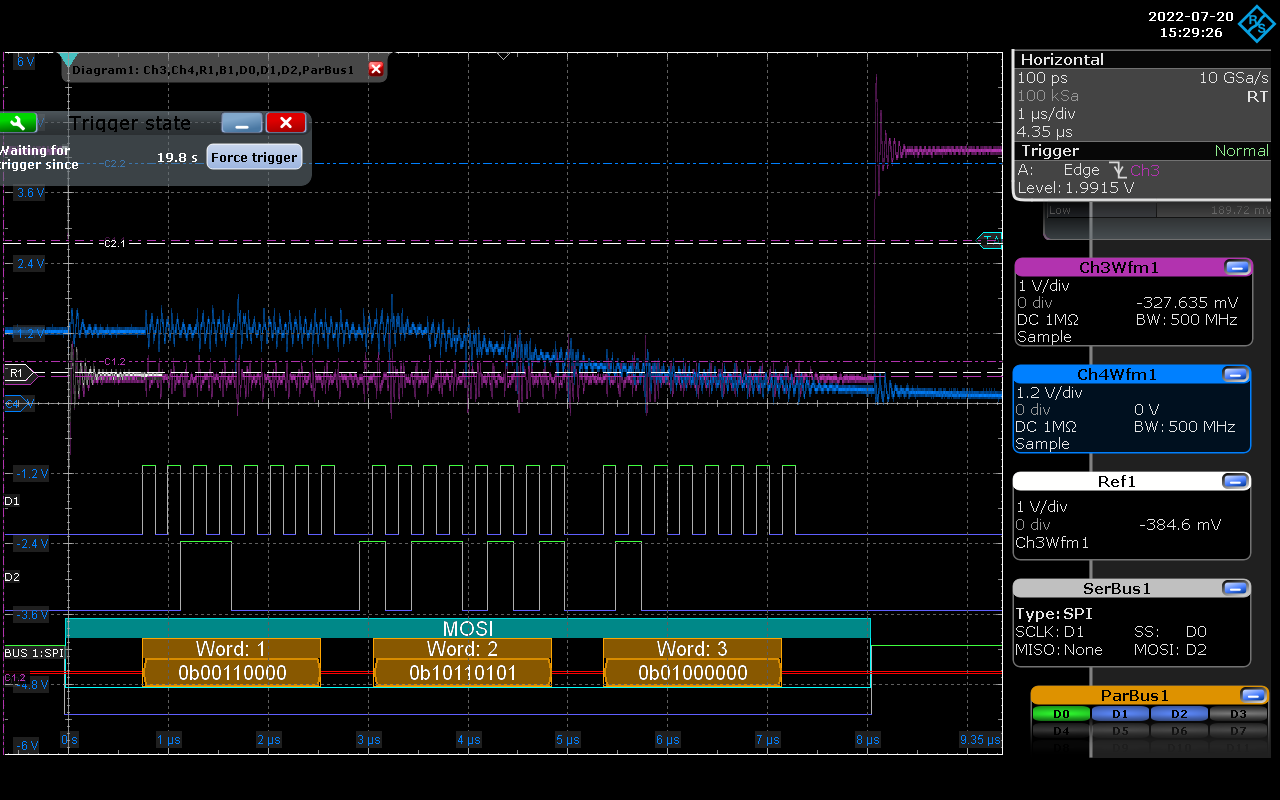
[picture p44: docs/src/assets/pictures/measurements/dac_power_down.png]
  
  \caption{DAC Power down process}\label{fig:meas:circ:dac_power_down}
\end{figure}

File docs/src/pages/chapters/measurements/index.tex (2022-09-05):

\chapter{Realworld Performance}
%
The upcoming section will discuss the performance of the circuit as well as the software of the speaker. A special focus is placed onto the beamforming characteristics.
%
\input{src/pages/chapters/measurements/circuit.tex}\clearpage
\input{src/pages/chapters/measurements/software.tex}\clearpage

\section{Beamforming}
\input{src/pages/chapters/measurements/methods.tex}
\input{src/pages/chapters/measurements/evaluation.tex}

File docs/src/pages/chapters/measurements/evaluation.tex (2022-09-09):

\subsection{Discussion}
%
In order to analyze the measurements the signal as well as the silence are loaded and fourier transformed. In the next step the silence is substracted from the signal in order to reduce the noise in the actual measurement.\enlargethispage{\baselineskip}\p
To display the beamforming characteristics of different AM and FM signals the amplitude of the corresponding frequency is picked from the frequency spectrum. This is done for every angle. In the end the power of the signal in relation to the highest value is calculated in $dB$. Figures \ref{fig:meas:beam:polar_meas_am} and \ref{fig:meas:beam:polar_meas_am} show the resulting characteristics.\p
For comparison a graph using the same number of transducers in a row ($5$) and the same distance between them ($10.5\,mm$) as the real speaker was created using the results from section \secref{sec:theory:beam}. It is displayed in figure \ref{fig:meas:beam:polar_calc}.
%
\begin{figure}
  \centering
  
  \caption{Measured beamforming characteristics of AM signals}\label{fig:meas:beam:polar_meas_am}
\end{figure}
%
\begin{figure}
  \centering
  
  \caption{Measured beamforming characteristics of FM signals}\label{fig:meas:beam:polar_meas_fm}
\end{figure}
\p
% side lobes
Both AM and FM signals show clear beamforming behaviour. Having said this the signal amplitude outside of the beam seems to be much higher for FM signals. Additionally, two side lobes at around $\pm 65^\circ$ can be observed not just in the measurements but the simulation too. They arise because the distance between the transducers is significantly higher than $\frac{\lambda}{2}$. This effect was already discussed in section \secref{sec:theory:beam}. While analyzing the results for all measured frequencies it was noticed that the power of the signal as well as the beamforming effect was smallest for signals between $1\,kHz$ and $2\,kHz$.
%
\begin{figure}
  \centering
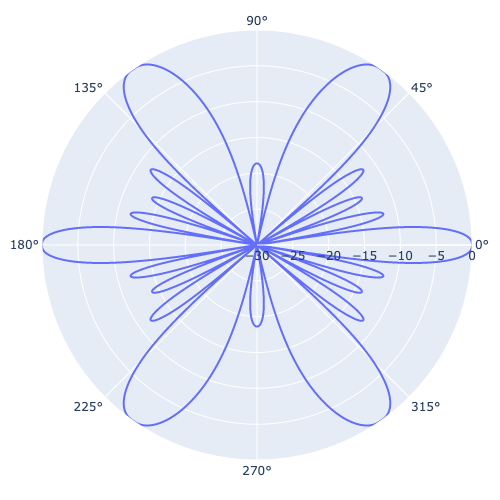
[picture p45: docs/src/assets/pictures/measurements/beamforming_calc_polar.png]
  
  \caption{Calculated beamforming characteristics}\label{fig:meas:beam:polar_calc}
\end{figure}

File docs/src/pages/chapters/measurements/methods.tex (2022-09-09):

\subsection{Measurement Setup}

The Goal of the measurements is to get an impression of the beamforming effect and compare it to the theoretical results from section \secref{sec:theory:beam}. As discussed in the previous sections the DAC and the software have some problems which could interfere with the result. Therefore the testsignal is generated by a waveform generator. Figure \ref{fig:meas:beam:setup} shows the measurement setup.
%
\begin{figure}[ht]
  \centering
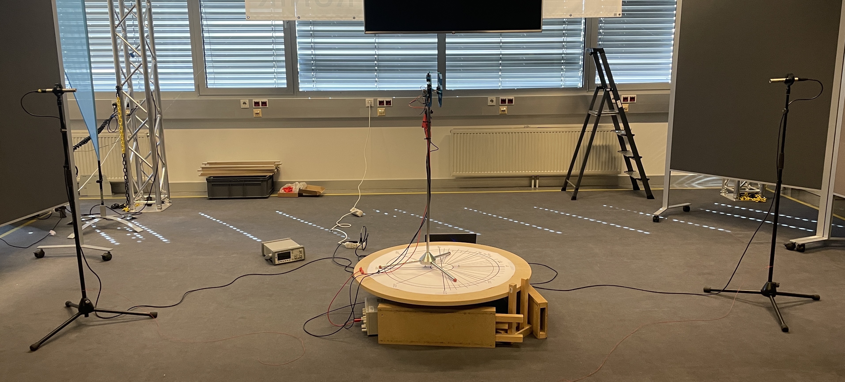
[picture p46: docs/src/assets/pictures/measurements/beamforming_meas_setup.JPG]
  
  \caption{Measurement setup}\label{fig:meas:beam:setup}
\end{figure}
\p
The speaker is positioned on a rotating table to measure the audio for different angles. Two condenser microphones are positioned in front and behind the speaker. This halves the number of measurements needed for a full rotation. The audio is recorded with a \textbf{Zoom H5} audio interface.\p
%
AM and FM modulated sine waves with different frequencies between $0\,Hz$ and $20\,kHz$ are used to measure the behaviour of the speaker. The exact parameters are shown in table \ref{tab:meas:beam:params}. Each frequency is recorded for $7\,s$. Additionally, $3\,s$ of silence are recorded which can be used to filter noise.
%
\begin{table}[ht]
  \caption{Measurement parameters}\label{tab:meas:beam:params}
  \begin{tabular}{l||c|c|c}
    & \textbf{Modulation Depth} & \textbf{Carrier frequency}  & \textbf{Amplitude}\\
    \hline
    \textbf{AM} & $0.8$         & $40kHz$                     & $2V$ \\
    \textbf{FM} & $5kHz$        & $40kHz$                     & $2V$ \\
  \end{tabular}
\end{table}

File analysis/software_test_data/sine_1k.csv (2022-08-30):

val | diff | time
2048 | 3837520169 | 3837485118
3252 | 11145 | 3837530117
100 | 10052 | 3837536419
3996 | 11145 | 3837547304
844 | 10937 | 3837559440
2048 | 24167 | 3837571314
3252 | 10834 | 3837597981
100 | 11094 | 3837609282
3996 | 10885 | 3837621470
844 | 9948 | 3837633397
2048 | 10260 | 3837644386
3252 | 19895 | 3837655271
100 | 10937 | 3837676677
3996 | 11302 | 3837688187
844 | 10104 | 3837700583
2048 | 10833 | 3837710531
3252 | 10833 | 3837723291
100 | 10208 | 3837737249
3996 | 18437 | 3837746259
844 | 10520 | 3837765842
2048 | 11198 | 3837777092
3252 | 10885 | 3837788290
100 | 11250 | 3837800998
3996 | 10990 | 3837813185
844 | 22916 | 3837824383
2048 | 10937 | 3837849331
3252 | 11145 | 3837864955
100 | 11302 | 3837872195
3996 | 10781 | 3837885267
844 | 11198 | 3837897038
2048 | 10989 | 3837908340
3252 | 22135 | 3837937454
100 | 10052 | 3837943548
3996 | 11042 | 3837954485
844 | 9792 | 3837967558
2048 | 11302 | 3837977193
3252 | 11354 | 3837991828
100 | 19166 | 3838001880
3996 | 10364 | 3838023078
844 | 11146 | 3838034171
2048 | 9844 | 3838045525
3252 | 11250 | 3838056150
100 | 11041 | 3838069275
3996 | 10886 | 3838080368
844 | 17917 | 3838105212
2048 | 10260 | 3838111305
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

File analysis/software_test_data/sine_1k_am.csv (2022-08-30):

val | diff | time
2048 | 7581240336 | 7581218720
2650 | 11719 | 7581246533
1074 | 10834 | 7581258513
3022 | 9897 | 7581270545
1446 | 11615 | 7581280076
2048 | 10625 | 7581293462
2650 | 11094 | 7581305233
1074 | 9896 | 7581319400
3022 | 10469 | 7581329505
1446 | 10573 | 7581340807
2048 | 10260 | 7581355183
2650 | 10886 | 7581361329
1074 | 10938 | 7581373204
3022 | 11302 | 7581385080
1446 | 11042 | 7581399768
2048 | 11198 | 7581410185
2650 | 10678 | 7581421435
1074 | 11250 | 7581433883
3022 | 10209 | 7581445342
1446 | 10886 | 7581457322
2048 | 10105 | 7581469353
2650 | 10885 | 7581480135
1074 | 11354 | 7581491125
3022 | 9688 | 7581505605
1446 | 11303 | 7581514928
2048 | 10938 | 7581527220
2650 | 10104 | 7581540502
1074 | 11094 | 7581550189
3022 | 10886 | 7581561336
1446 | 11302 | 7581573940
2048 | 9896 | 7581585451
2650 | 10105 | 7581598420
1074 | 10000 | 7581609514
3022 | 11095 | 7581619098
1446 | 10000 | 7581632536
2048 | 11042 | 7581642067
2650 | 11146 | 7581653214
1074 | 11094 | 7581666079
3022 | 10834 | 7581677381
1446 | 11355 | 7581689986
2048 | 9792 | 7581702694
2650 | 10000 | 7581713476
1074 | 10261 | 7581724310
3022 | 11042 | 7581735248
1446 | 10938 | 7581746394
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

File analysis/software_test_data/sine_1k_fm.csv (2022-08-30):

val | diff | time
2048 | 25184284810 | 25184263560
3252 | 10364 | 25184291008
100 | 11197 | 25184301216
3996 | 11094 | 25184312414
844 | 10990 | 25184326893
2048 | 10729 | 25184336372
3252 | 10208 | 25184350382
100 | 11146 | 25184359132
3996 | 11145 | 25184371216
844 | 11823 | 25184387049
2048 | 11979 | 25184401215
3252 | 11354 | 25184415330
100 | 10938 | 25184427830
3996 | 11198 | 25184438507
844 | 11302 | 25184451632
2048 | 10313 | 25184461423
3252 | 11563 | 25184473558
100 | 10937 | 25184485225
3996 | 9948 | 25184499444
844 | 11302 | 25184507985
2048 | 10885 | 25184521058
3252 | 11250 | 25184532100
100 | 10833 | 25184545225
3996 | 10052 | 25184557256
844 | 10261 | 25184568245
2048 | 10834 | 25184579235
3252 | 11042 | 25184590953
100 | 10990 | 25184603037
3996 | 11198 | 25184614078
844 | 10938 | 25184627047
2048 | 11302 | 25184638088
3252 | 11146 | 25184652619
100 | 10729 | 25184662515
3996 | 11093 | 25184674911
844 | 10156 | 25184686213
2048 | 10833 | 25184697255
3252 | 11250 | 25184709754
100 | 11093 | 25184722046
3996 | 10052 | 25184735483
844 | 10834 | 25184745067
2048 | 11250 | 25184756108
3252 | 10989 | 25184770744
100 | 10156 | 25184782566
3996 | 10938 | 25184792150
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

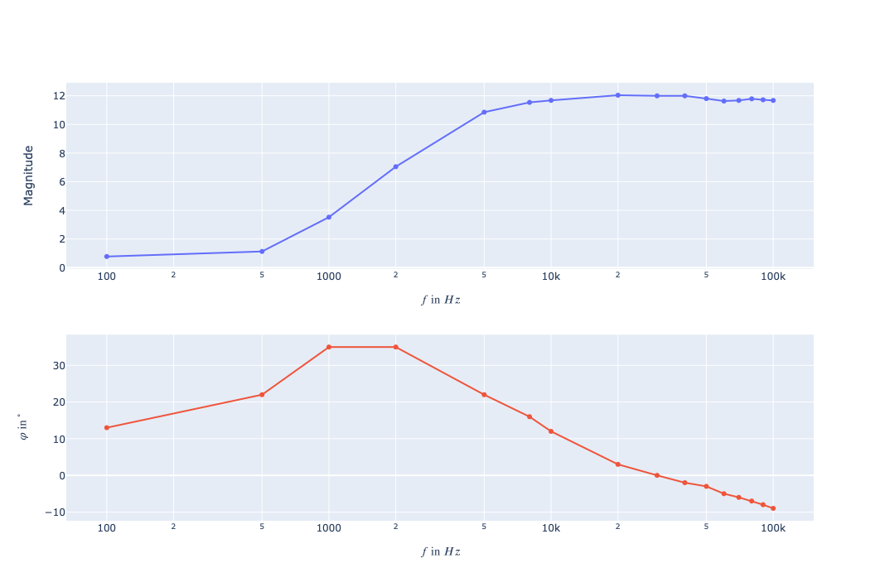
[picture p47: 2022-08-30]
docs/src/assets/pictures/measurements/amp_bode.png

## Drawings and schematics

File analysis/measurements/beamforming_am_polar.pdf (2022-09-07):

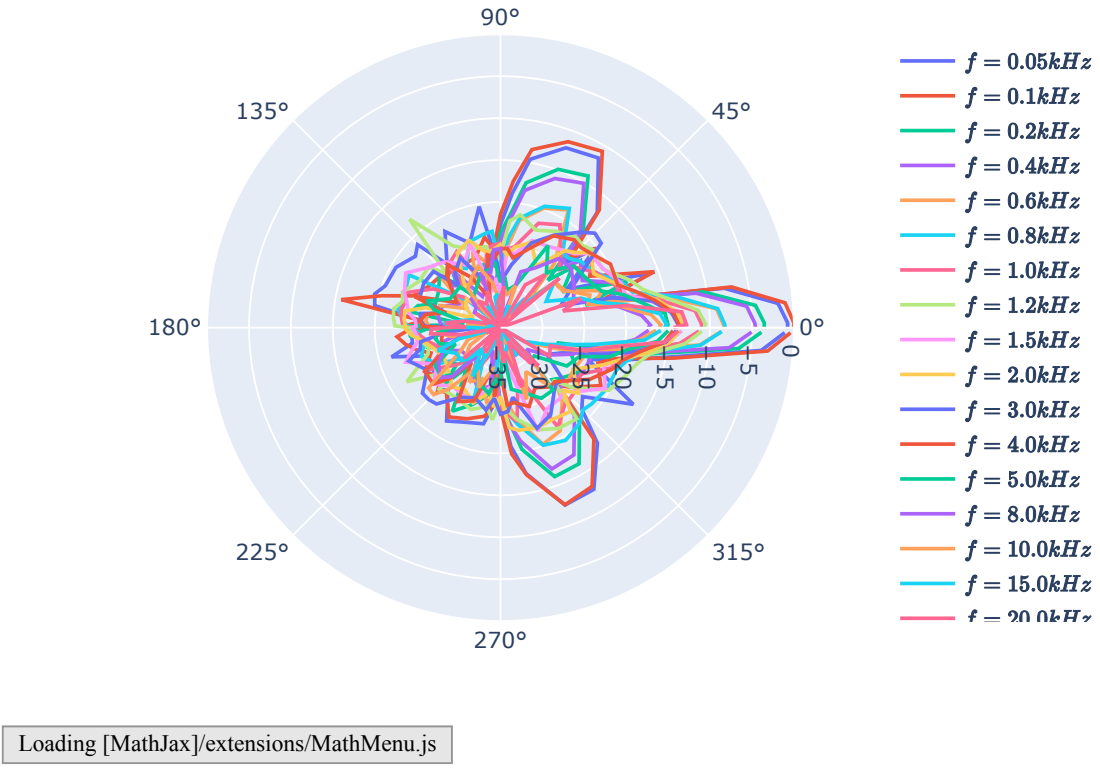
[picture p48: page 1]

Loading [MathJax]/extensions/MathMenu.js

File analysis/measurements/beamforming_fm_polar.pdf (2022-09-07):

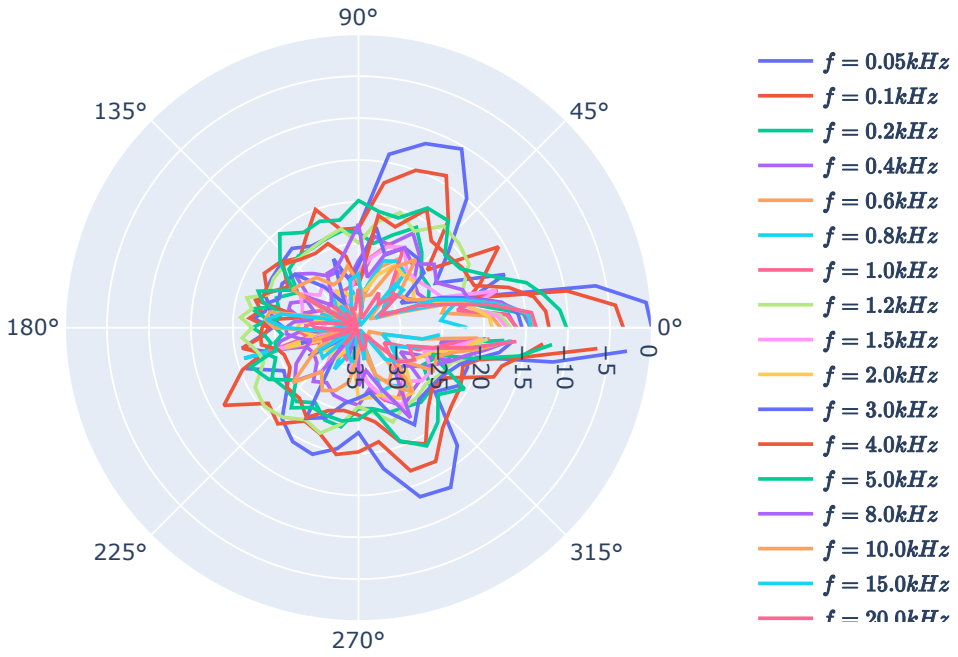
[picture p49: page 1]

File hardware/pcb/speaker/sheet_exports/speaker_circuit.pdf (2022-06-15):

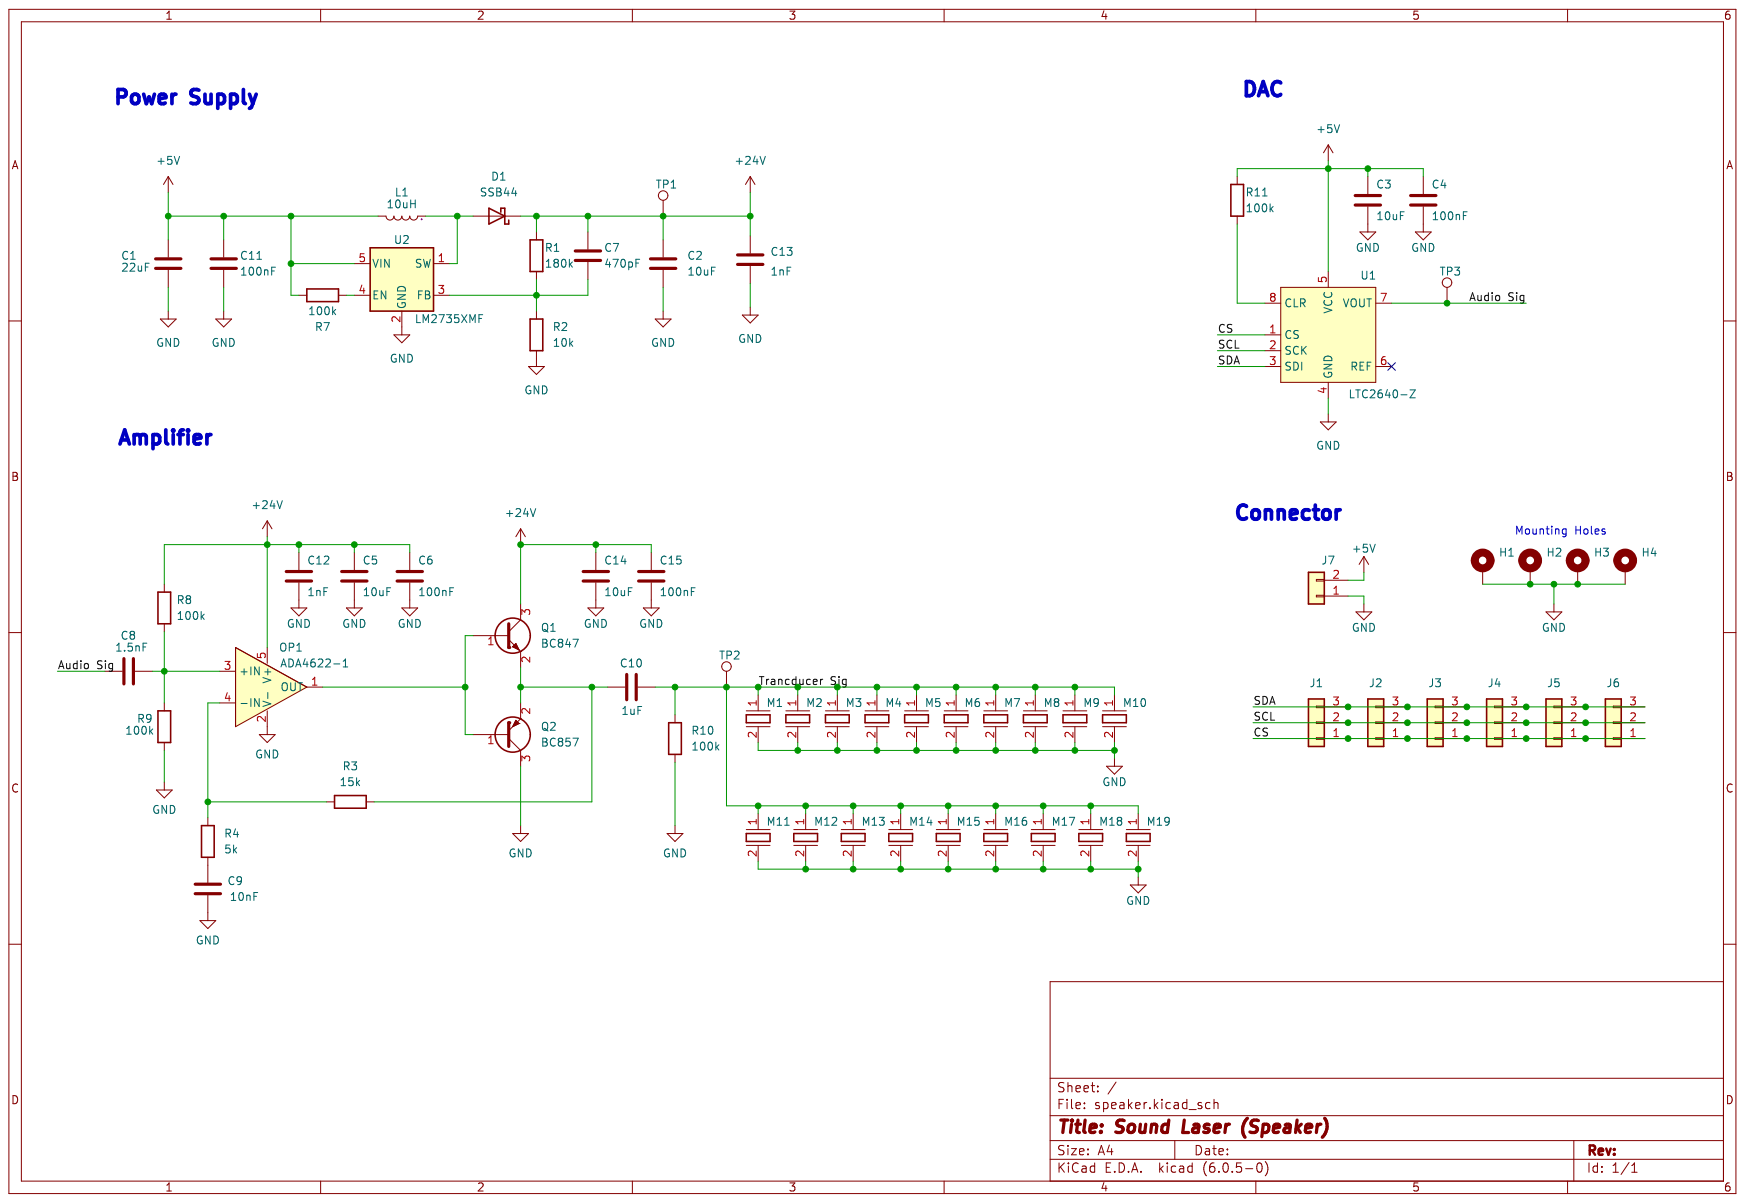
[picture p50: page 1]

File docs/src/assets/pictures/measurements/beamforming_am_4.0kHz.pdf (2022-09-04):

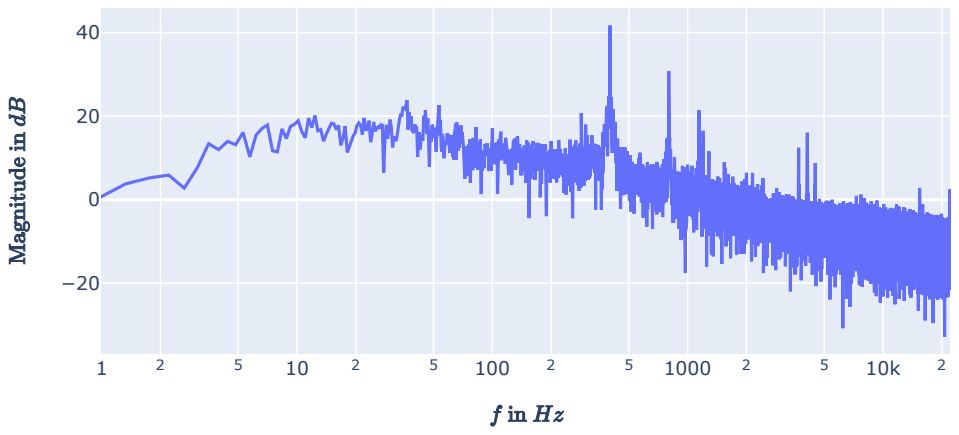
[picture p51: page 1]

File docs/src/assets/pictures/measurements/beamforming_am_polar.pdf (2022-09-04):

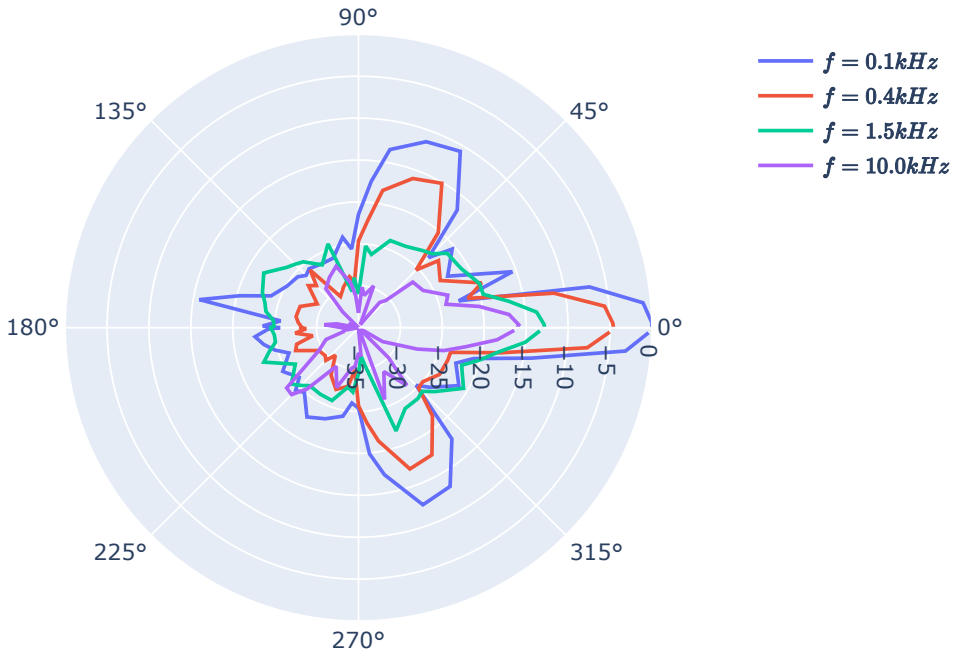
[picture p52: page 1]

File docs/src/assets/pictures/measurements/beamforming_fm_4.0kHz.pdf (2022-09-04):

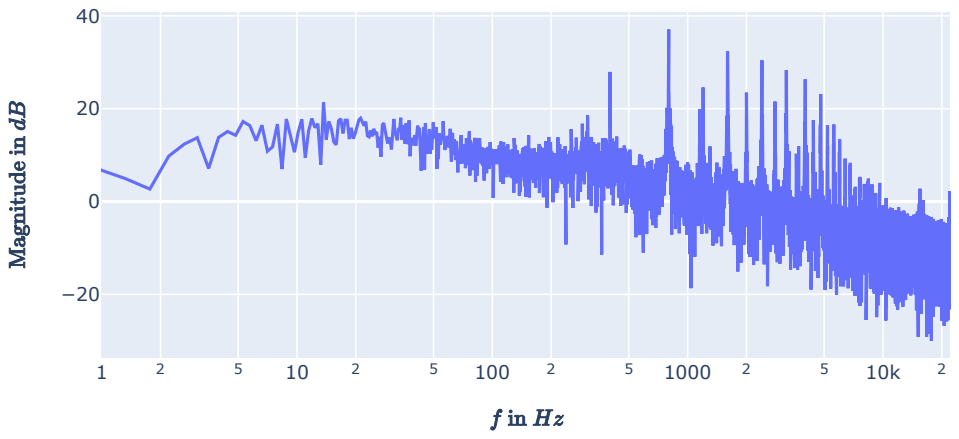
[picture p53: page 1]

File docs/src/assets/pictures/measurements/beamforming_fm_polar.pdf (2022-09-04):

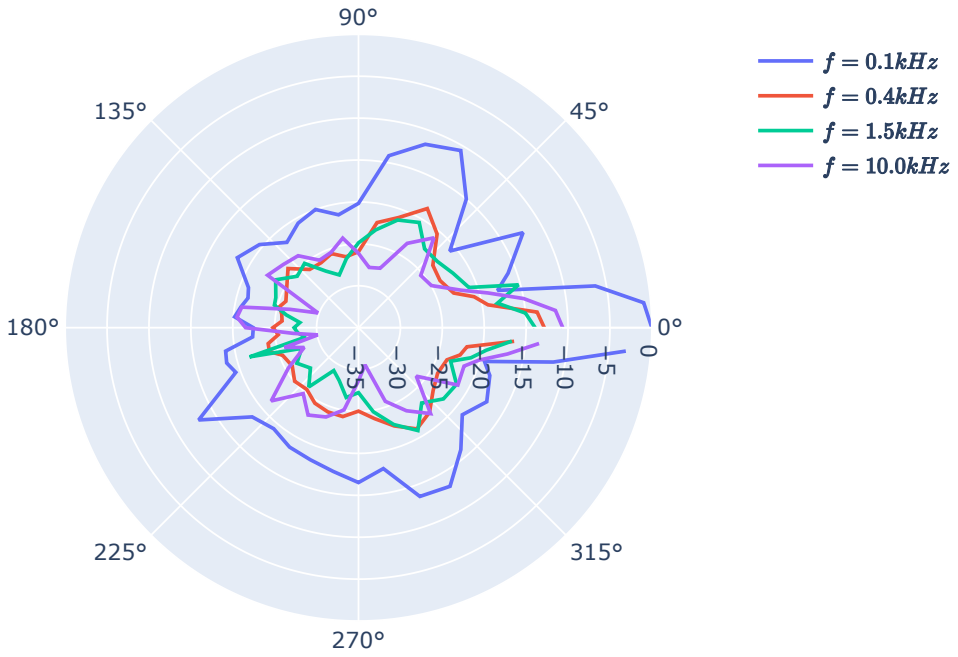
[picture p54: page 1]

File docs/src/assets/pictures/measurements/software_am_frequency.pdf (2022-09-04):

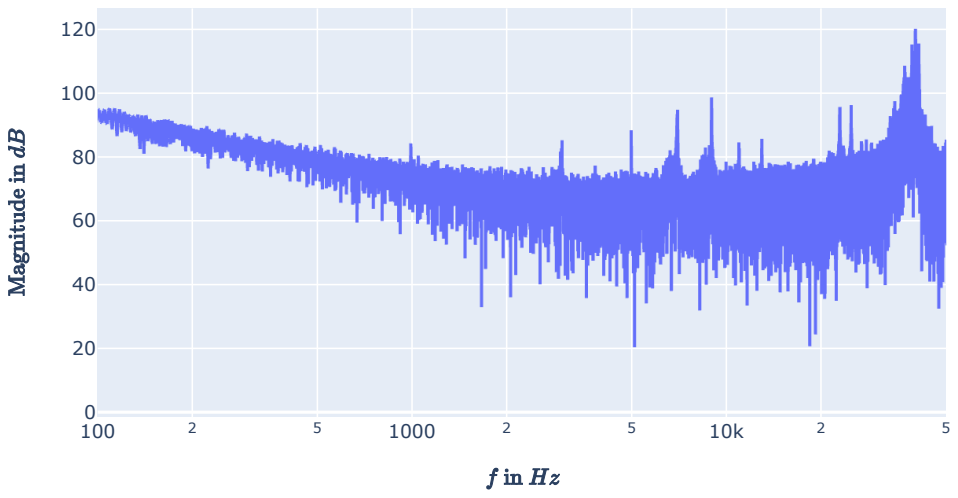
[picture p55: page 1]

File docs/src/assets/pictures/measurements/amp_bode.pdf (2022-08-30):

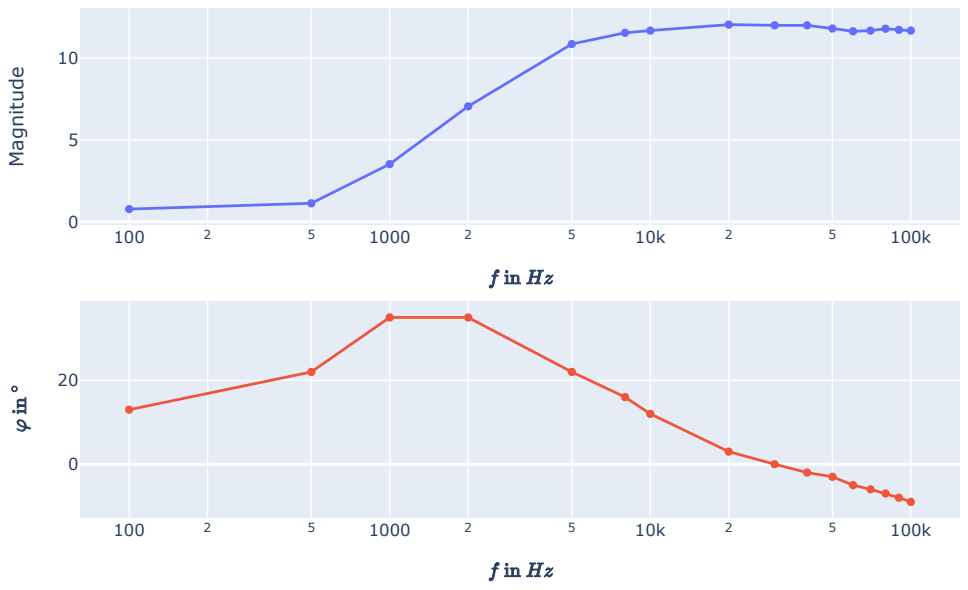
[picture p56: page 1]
Magnitude

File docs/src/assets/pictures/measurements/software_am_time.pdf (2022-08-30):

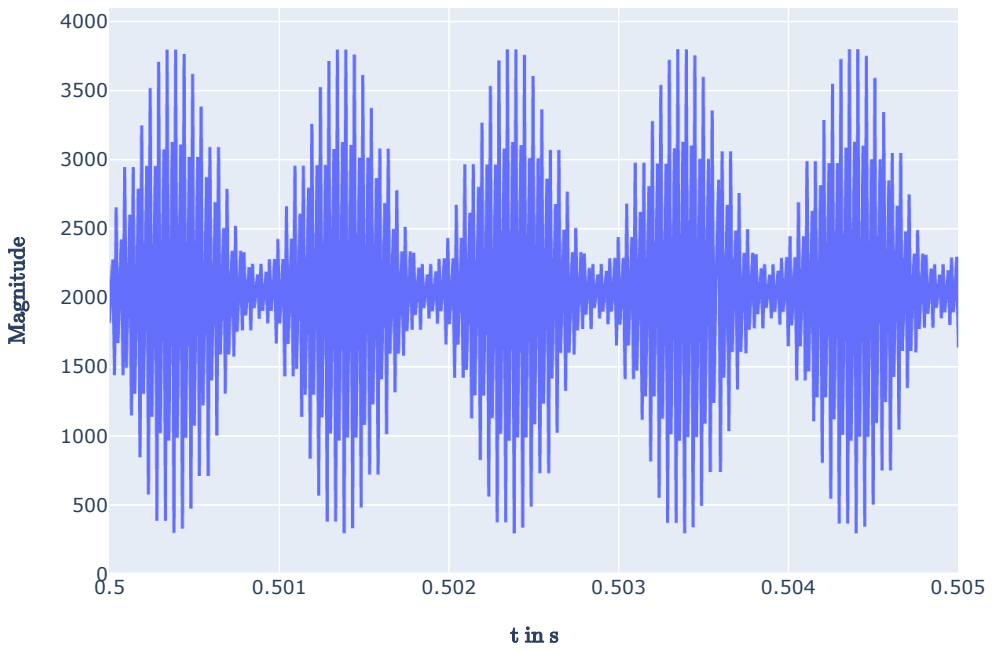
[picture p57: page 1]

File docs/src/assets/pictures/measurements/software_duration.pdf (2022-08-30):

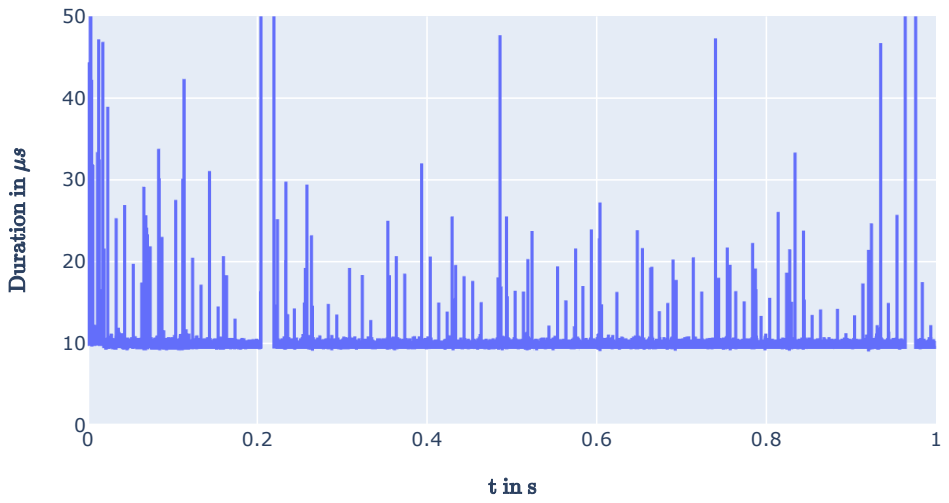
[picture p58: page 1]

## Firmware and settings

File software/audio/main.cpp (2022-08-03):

#include <chrono>
#include <csignal>
#include <cstdlib>
#include <iostream>
#include <stdio.h>
#include <stdlib.h>
#include <thread>
#include <vector>

#include "audio.hpp"
#include "speaker.hpp"
#include "table.hpp"

Table* Table::instance_ = { nullptr };

void exit_handler(int s) {
  // Table::instance()->printSignal();
  exit(0);
}

int main(int, char**) {
  std::cout << "Welcome to Sound Laser!\n";

  struct sigaction sig_int_handler = {
    .sa_flags = 0,
  };
  sig_int_handler.sa_handler = &exit_handler;
  sigemptyset(&sig_int_handler.sa_mask);
  sigaction(SIGINT, &sig_int_handler, NULL);

  Table::instance()->configureSignalLen(100000);

  if (!bcm2835_init()) {
    std::cerr << "bcm2835_init failed. Are you running as root??\n";
    return 1;
  }

  Speaker* speaker = Speaker::instance();
  AudioProcessor* audio = AudioProcessor::instance();

  speaker->configure(100000, 4096, 0);
  audio->configure(16000, 512);

  const auto spe = speaker->run_thread();
  // const auto aud = audio->run_thread();
  // const auto rec = audio->record_thread();

  uint16_t sample = 4000;
  string input_buff;

  while (sample >= 0) {
    getline(std::cin, input_buff);
    std::cout << sample << "\n";
    speaker->samples.push(sample);
    sample -= 100;
  }

  // spe->join();
  // aud->join();
  // rec->join();

  bcm2835_close();

  return 0;
}

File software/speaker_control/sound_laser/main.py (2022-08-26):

from gpiozero.pins.pigpio import PiGPIOFactory
from gpiozero import Device

import argparse
import os.path as path
import numpy as np

from sound_laser.server import Server

BASE_PATH = path.abspath(path.dirname(__file__))
WWW_PATH = path.join(path.dirname(BASE_PATH), "www")


def main():
    """ Entrypoint of the movement control programm"""
    np.seterr(all="warn")


    parser = argparse.ArgumentParser()
    parser.add_argument(
        "-p", "--port", help="Port on wich the webserver will listen", type=int, default=8080)
    parser.add_argument(
        "-d", "--dir", help="Directory wich includes your html, css and js files", default=WWW_PATH)
    args = parser.parse_args()

    Device.pin_factory = PiGPIOFactory()
    server = Server(args.port, args.dir)
    server.open()


if __name__ == "__main__":
    main()

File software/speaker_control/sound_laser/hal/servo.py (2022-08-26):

from gpiozero import Servo
from sound_laser.hal import HAL


class ServoHAL(HAL):
    """Hardware interface to control a servo

    Attributes:
        pin: number of the GPIO pin used to control the servo
    """

    def __init__(self, pin: int, inverted: bool, offset: float):
        """Initialize servo

        Args:
            pin(int): Pin to which the signal wire of the servo is connected (12, 13, 18, 19 for hardware PWM)
            inverted (bool): defines if the rotation of the servo should be inverted
        """

        self.pin = pin
        self.offset = offset
        self.inverted = -1 if inverted else 1

        self.pwm = Servo(pin, initial_value=self._map_position(0), min_pulse_width=0.615 /
                         1000, max_pulse_width=2.495 / 1000)

    def _map_position(self, angle: float):
        """Calculate servo positon from angle

        Args:
           angle (float): Angle in degree
        """

        pos = self.inverted * (angle + self.offset) / 90

        if pos > 1: pos = 1
        if pos < -1: pos = -1

        return pos

    def set_position(self, pos: float):
        """Set the position of the servo

        Args:
            pos: Servoposition in degree between -90 and 90
        """
        self.pwm.value = self._map_position(pos)

    def close(self):
        """
            Release servo
        """
        self.pwm.value = None

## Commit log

2022-03-15 ADD circuit and pcb design
    [sound_laser.kicad_pcb, sound_laser.kicad_sch, ultrasonic_transducer.step]
2022-03-18 ADD i2c Resistor calculation, REWORK power supplay
    [circuit_board.STEP, power_supply_1A.kicad_sch, sound_laser.csv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]
2022-03-25 REWORK circuit board
    [circuit_board.STEP, sound_laser-B_Mask.dxf, sound_laser-B_Paste.dxf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]
2022-03-25 REWORK file structure
    [power_supply_1A.kicad_sch, raspberry_shield.kicad_pcb, raspberry_shield.kicad_sch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]
2022-03-25 ADD vcc distributor, ADD raspberry shield
    [raspberry_shield.kicad_pcb, raspberry_shield.kicad_sch, vcc_distributor.kicad_pcb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]
2022-03-30 REWORK pcb design
    [inductor_wuerth_5030.step, speaker.kicad_pcb, speaker.kicad_sch]
2022-04-05 REWORK pcb layout, ADD BOM
    [BOM.xlsx, circuit_board.STEP, speaker.kicad_pcb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]
2022-04-16 REV 3
    [speaker.kicad_pcb, speaker.kicad_sch]
2022-04-23 add pcb gbr files
    [BOM.xlsx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]
2022-05-14 update gerber files
    [BOM.xlsx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]
2022-06-15 UPDATE BOM
    [BOM.xlsx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]
2022-06-20 rework backplate, test circuit
    [BOM.xlsx, backplate.3mf, circuit_board.STEP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]
2022-06-24 add spi write demo, add bluealsa install guide
2022-07-04 rework pcb mount model
    [base_plate_demo.3mf, base_plate_demo_backplate.3mf, pcb_mount.3mf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]
2022-07-04 add pcm and spi interface, add speaker loop
2022-07-05 rework movement calculation
    [3:8UMC_hole.3mf, M3_hole_demo.3mf, side_mount_demo.3mf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]
2022-07-08 fix queue and audio processor errors
    [main.cpp]
2022-07-11 fix threading problems, fix record buffer length
    [main.cpp]
2022-07-12 fix modulation, rework audio process loop for better performance, rework pcm::readFrames with matching type
    [main.cpp]
2022-07-12 add software test/analyze methods
    [BOM.xlsx, pcb_mount.3mf, pcb_plate.3mf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]
2022-07-13 add FM, rework speaker loop to optimize timing
    [main.cpp]
2022-07-14 add software tests
    [queue_size.csv, sine_time.csv]
2022-07-14 rework file structure, add movement control basic
    [main.cpp, main.py]
2022-07-15 rework file structure, add basic website, add SpeakerControll class
    [main.cpp, main.py]
2022-07-15 add install script, add systemd services, fix speaker_control installation
    [server.py, speaker.py]
2022-07-21 test software
    [pcb_base.3mf, pcb_base.stl, sine_time.csv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]
2022-07-25 add measurment signal generation
    [pcb_mount.3mf]
2022-07-28 Squashed commit of the following:
    commit 3fa4e4c12e53fee62d526cc16bea1332eb74206b
    Author: Lukas Schüttler <lukas.schuettler@ise-technology.com>
    Date: Thu Jul 28 15:27:50 2022 +0200
    remove signal files
    commit 1cc97697839b0cc17f122b4d75ed0b6a5e3f3031
    Author: Lukas Schüttler <lukas.schuettler@ise-technology.com>
    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
2022-08-05 add circuitdesign, construction and software chapter
2022-08-12 rework thesis, add construction sketches
    [bode_messung.csv, trans_meas.csv]
2022-08-26 rework beamforming/modulation plots
    [BOM.xlsx]
2022-08-30 rework plots, fix measurements
    [queue_size.csv, sine.csv, sine_1k.csv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]
2022-09-04 rework flowchart
2022-09-07 clean up
    [3:8UMC_hole.3mf, M3_hole_demo.3mf, backplate.3mf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]
